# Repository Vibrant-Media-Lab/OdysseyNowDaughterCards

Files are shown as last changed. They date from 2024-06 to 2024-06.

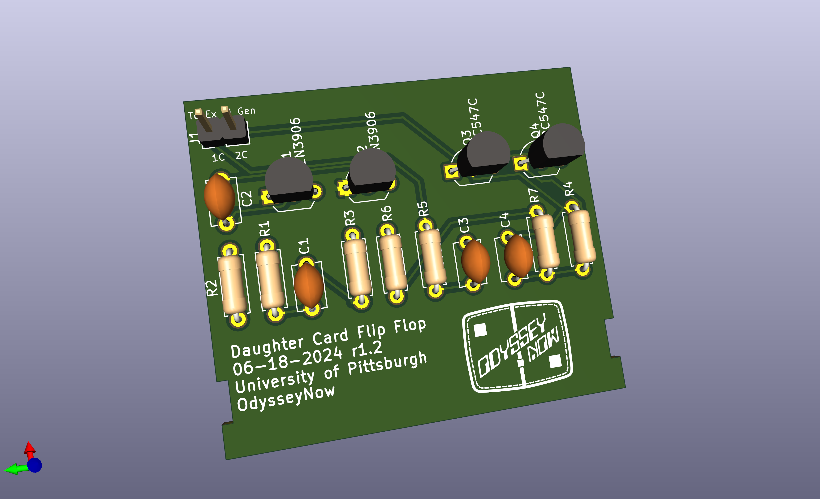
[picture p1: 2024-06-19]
OdysseyDaughterCardFlipFlop/images/OdysseyDaughterCardFlipFlop.png

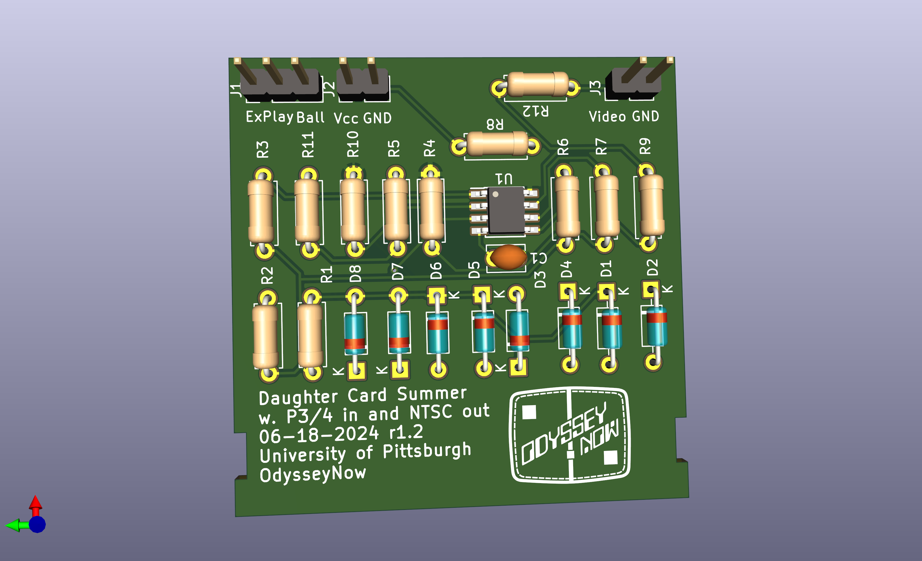
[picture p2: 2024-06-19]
OdysseyDaughterCardSummer/images/OdysseyDaughterCardSummer.png

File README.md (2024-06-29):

# Odyssey Now Daughter Cards

Replacement daughter card schematics and layouts for the Magnavox Odyssey BLAK version.

## Layout
* `OdysseyDaughterCard<name>` (KiCad 8 project)
  * `3D_models/` (WRL and STEP files for the board)
  * `footprints/` (non-standard footprint libraries for project)
  * `gerbers/` (last generated gerbers for layout)
  * `images/` (a render of the board)
  * `pdf/` (pdfs of schematic and layout)
  * `symbols/` (non-standard symbol libraries for project)
  * `dimensions.txt` (board dimension in meters for easier ordering from places like AllPCB)

## Bill of Materials
* See OdysseyDaughtCardsBillOfMaterials.xlsx for a list components used in the last round of boards made in the VML.

## License
* Designed by Levi Burner and Zachary Horton
* Each card's design is available under Creative Commons Attribution. All license text must be included in any redistribution and attribution must be given to original design and designers. See LICENSE.txt in each card's folder for additional details.

## Old Designs (legacy)
The original git history for each card (including old prototypes that were made and are likely to be floating around in the VML) be found on the `legacy-*` branches.

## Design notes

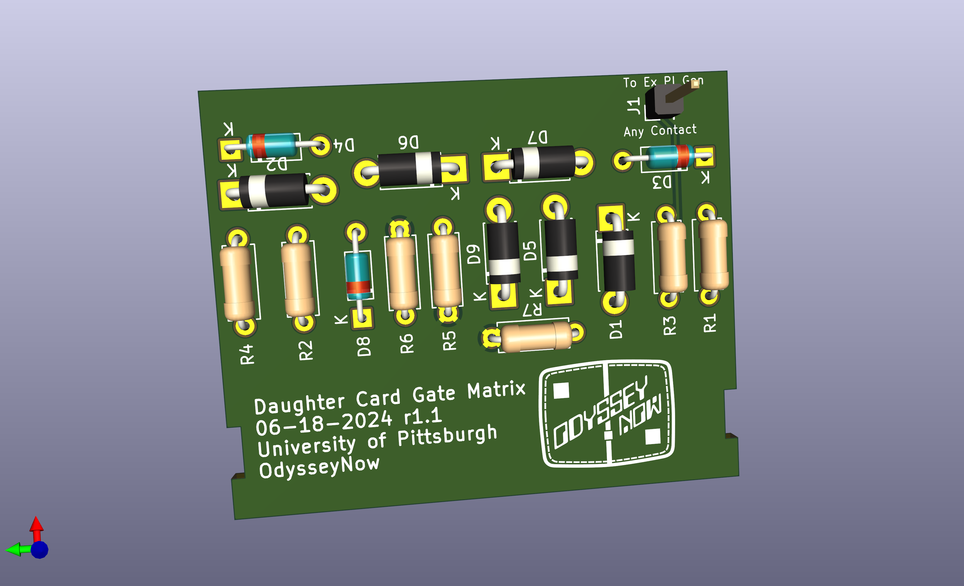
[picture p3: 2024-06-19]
OdysseyDaughterCardGateMatrix/images/OdysseyDaughterCardGateMatrix.png

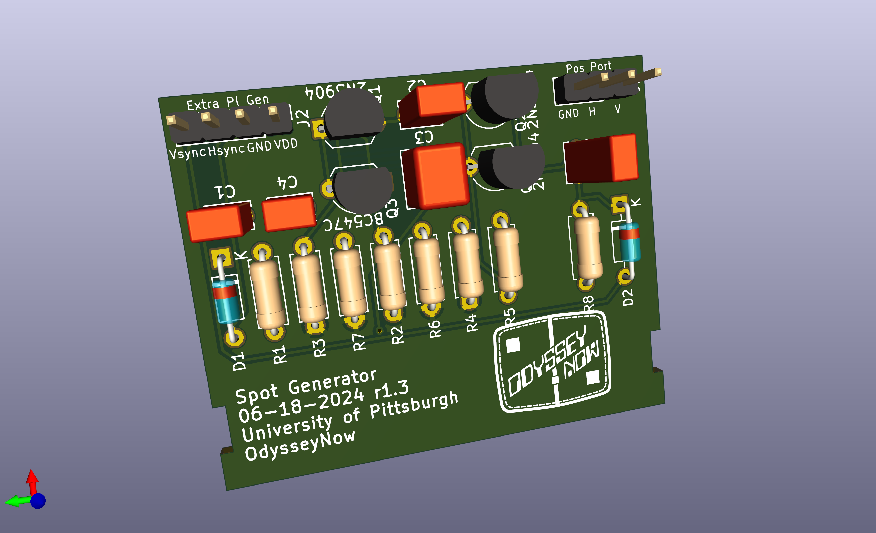
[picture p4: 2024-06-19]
OdysseyDaughterCardSpotGenerator/images/OdysseyDaughterCardSpotGenerator.png

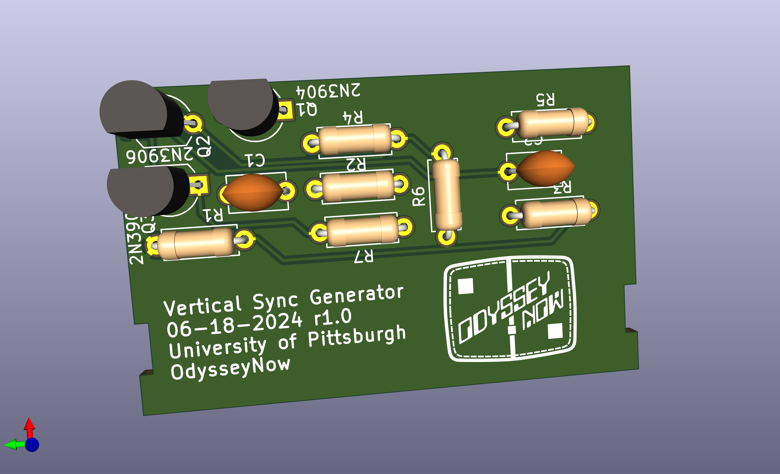
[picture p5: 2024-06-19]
OdysseyDaughterCardVertSyncGenerator/images/OdysseyDaughterCardVertSyncGenerator.png

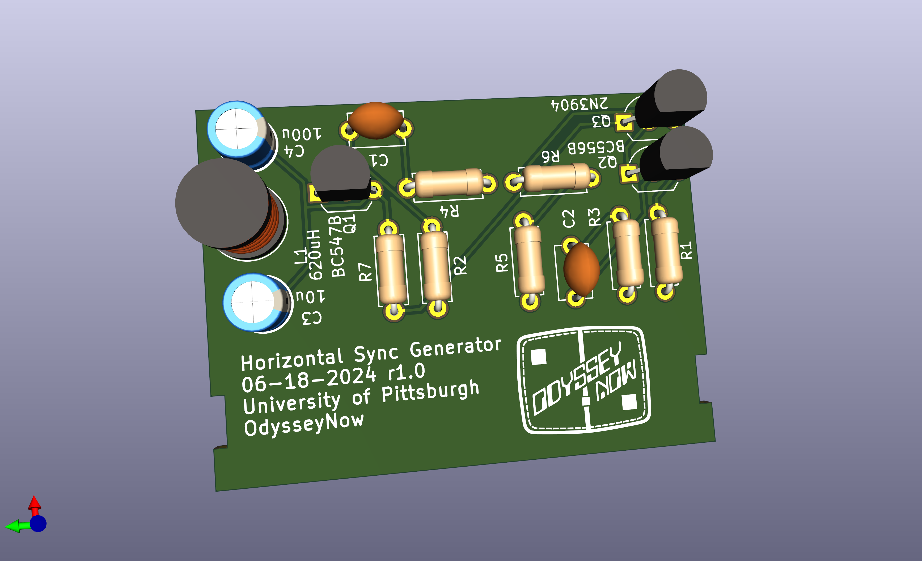
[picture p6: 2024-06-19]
OdysseyDaughterCardHorizSyncGenerator/images/OdysseyDaughterCardHorizSyncGenerator.png

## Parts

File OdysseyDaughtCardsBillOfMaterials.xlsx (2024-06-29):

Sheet: Master Parts List
 |  |  |  |  |  | # Parts | 19 | 12 | 15 | 19 | 15 | 11
 |  |  |  |  |  | Non PCB Cost Per Unit (10pcs) | $1.61 | $2.27 | $1.64 | $2.07 | $2.07 | $1.18
 |  |  |  |  |  | Non PCB Cost Per Unit (100pcs) | $0.81 | $1.19 | $0.79 | $1.01 | $1.09 | $0.55
Type | Value | P/N | Link | Notes | CPU (10pcs) | CPU (100pcs) (prices are from 2019) | Flip Flop | Gate Matrix | Horiz Sync Generator | Spot Gen | Summer | Vert Sync Generator
Capacitor | 0.01u | BC2662CT-ND | https://www.digikey.com/product-detail/en/vishay-bc-components/K103K10X7RF5UH5/BC2662CT-ND/2356876 |  | $0.118 | $0.0599 |  |  |  | 1
Capacitor | 0.15u | 445-173584-1-ND | https://www.digikey.com/product-detail/en/tdk-corporation/FG28X7R1E154KNT06/445-173584-1-ND/5812189 |  | $0.180 | $0.1021 |  |  |  | 1
Capacitor | 0.1u | BC2665CT-ND | https://www.digikey.com/product-detail/en/vishay-bc-components/K104K10X7RF5UH5/BC2665CT-ND/2356879 |  | $0.160 | $0.0809 | 2 |  |  | 1 |  | 2
Capacitor | 100p | BC2657CT-ND | https://www.digikey.com/product-detail/en/vishay-bc-components/K101K10X7RF5UH5/BC2657CT-ND/2356871 |  | $0.122 | $0.0621 | 2
Capacitor | 100u | 399-6602-ND | https://www.digikey.com/product-detail/en/kemet/ESK107M6R3AC3AA/399-6602-ND/3083017 |  | $0.114 | $0.0534 |  |  | 1
Capacitor | 10u | 399-6597-ND | https://www.digikey.com/product-detail/en/kemet/ESK106M016AC3AA/399-6597-ND/3083012 |  | $0.105 | $0.0493 |  |  | 1
Capacitor | 120p | BC2669CT-ND | https://www.digikey.com/product-detail/en/vishay-bc-components/K121K10X7RF5UH5/BC2669CT-ND/2356883 |  | $0.120 | $0.0608 |  |  |  | 1
Capacitor | 1500p | 445-173589-1-ND | https://www.digikey.com/product-detail/en/tdk-corporation/FG28X7R1H152KNT06/445-173589-1-ND/5812194 |  | $0.180 | $0.1021 |  |  |  | 1
Capacitor | 470p | BC2681CT-ND | https://www.digikey.com/product-detail/en/vishay-bc-components/K471K10X7RF5UH5/BC2681CT-ND/2356895 |  | $0.120 | $0.0608 |  |  | 1
Capacitor | 680p | BC2690CT-ND | https://www.digikey.com/product-detail/en/vishay-bc-components/K681K10X7RF5UH5/BC2690CT-ND/2356904 |  | $0.123 | $0.0625 |  |  | 1
Diode | 1N4448 | 1N4448FS-ND | https://www.digikey.com/product-detail/en/on-semiconductor/1N4448/1N4448FS-ND/978532 |  | $0.087 | $0.0473 |  | 3 |  | 2 | 8
Diode | BAT83S | BAT83S-TRGICT-ND | https://www.digikey.com/product-detail/en/vishay-semiconductor-diodes-division/BAT83S-TR/BAT83S-TRGICT-ND/8564711 |  | $0.314 | $0.1664 |  | 6 |  |  | 4
Inductor | 620uH 9 Ohm | RLB0608-681KL-ND | https://www.digikey.com/product-detail/en/bourns-inc/RLB0608-681KL/RLB0608-681KL-ND/2561280 |  | $0.314 | $0.1664 |  |  | 1
Resistor | 470 | CF14JT470RCT-ND | https://www.digikey.com/product-detail/en/stackpole-electronics-inc/CF14JT470R/CF14JT470RCT-ND/1830342 |  | $0.040 | $0.0162 |  |  | 1 |  |  | 2
Resistor | 820 | CF14JT820RCT-ND | https://www.digikey.com/product-detail/en/stackpole-electronics-inc/CF14JT820R/CF14JT820RCT-ND/1830348 |  | $0.040 | $0.0162 |  |  | 1 |  | 1 | 1
Resistor | 100k | CF14JT100KCT-ND | https://www.digikey.com/product-detail/en/stackpole-electronics-inc/CF14JT100K/CF14JT100KCT-ND/1830399 |  | $0.040 | $0.0162 |  |  |  | 1
Resistor | 10k | CF14JT10K0CT-ND | https://www.digikey.com/product-detail/en/stackpole-electronics-inc/CF14JT10K0/CF14JT10K0CT-ND/1830374 |  | $0.040 | $0.0162 |  |  |  | 5
Resistor | 150k | CF14JT150KCT-ND | https://www.digikey.com/product-detail/en/stackpole-electronics-inc/CF14JT150K/CF14JT150KCT-ND/1830403 |  | $0.040 | $0.0162 |  |  | 1
Resistor | 180k | CF14JT180KCT-ND | https://www.digikey.com/products/en?keywords=CF14JT180KCT-ND |  | $0.040 | $0.0162 |  |  |  |  |  | 1
Resistor | 18k | CF14JT18K0CT-ND | https://www.digikey.com/product-detail/en/stackpole-electronics-inc/CF14JT18K0/CF14JT18K0CT-ND/1830381 |  | $0.040 | $0.0162 |  |  |  |  | 1
Resistor | 1k | CF14JT1K00CT-ND | https://www.digikey.com/product-detail/en/stackpole-electronics-inc/CF14JT1K00/CF14JT1K00CT-ND/1830350 |  | $0.040 | $0.0162 | 2 |  | 2
Resistor | 2.2k | CF14JT2K20CT-ND | https://www.digikey.com/product-detail/en/stackpole-electronics-inc/CF14JT2K20/CF14JT2K20CT-ND/1830358 |  | $0.040 | $0.0162 | 1 |  |  | 1 |  | 1
Resistor | 270k | CF14JT270KCT-ND | https://www.digikey.com/product-detail/en/stackpole-electronics-inc/CF14JT270K/CF14JT270KCT-ND/1830409 |  | $0.040 | $0.0162 |  |  |  | 1
Resistor | 27k | CF14JT27K0CT-ND | https://www.digikey.com/product-detail/en/stackpole-electronics-inc/CF14JT27K0/CF14JT27K0CT-ND/1830385 |  | $0.040 | $0.0162 |  |  |  |  | 1
Resistor | 3.3k | CF14JT3K30CT-ND | https://www.digikey.com/product-detail/en/stackpole-electronics-inc/CF14JT3K30/CF14JT3K30CT-ND/1830362 |  | $0.040 | $0.0162 |  |  | 1
Resistor | 300k | CF14JT300KCT-ND | https://www.digikey.com/product-detail/en/stackpole-electronics-inc/CF14JT300K/CF14JT300KCT-ND/1830410 |  | $0.040 | $0.0162 |  |  | 1 |  |  | 1
Resistor | 4.7k | CF14JT4K70CT-ND | https://www.digikey.com/product-detail/en/stackpole-electronics-inc/CF14JT4K70/CF14JT4K70CT-ND/1830366 |  | $0.040 | $0.0162 |  | 3
Resistor | 47k | CF14JT47K0CT-ND | https://www.digikey.com/product-detail/en/stackpole-electronics-inc/CF14JT47K0/CF14JT47K0CT-ND/1830391 |  | $0.040 | $0.0162 | 4
Switch/Button | Slide Switch SPDT Through Hole, Right Angle | CKN9559-ND | https://www.digikey.com/product-detail/en/c-k/OS102011MA1QN1/CKN9559-ND/1981430 |  |  |  | 4
Transistor | 2N3904 | 2N3904FS-ND | https://www.digikey.com/product-detail/en/on-semiconductor/2N3904BU/2N3904FS-ND/1413 |  | $0.210 | $0.0916 |  |  | 1 | 3 |  | 2
Transistor | 2N3906 | 2N3906TARFSCT-ND | https://www.digikey.com/product-detail/en/on-semiconductor/2N3906TAR/2N3906TARFSCT-ND/3478146 |  | $0.195 | $0.1035 | 2 |  |  |  |  | 1
Transistor | BC547B | BC547BTACT-ND | https://www.digikey.com/product-detail/en/on-semiconductor/BC547BTA/BC547BTACT-ND/1532789 |  | $0.181 | $0.0962 |  |  | 1
Transistor | BC547C | BC547CBU-ND | https://www.digikey.com/product-detail/en/on-semiconductor/BC547CBU/BC547CBU-ND/975543 |  | $0.190 | $0.1005 | 2 |  |  | 1
Transistor | BC556B | BC556BTACT-ND | https://www.digikey.com/product-detail/en/on-semiconductor/BC556BTA/BC556BTACT-ND/3042483 |  | $0.188 | $0.0999 |  |  | 1

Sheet: Digikey Order Generator
This sheet can be used to generate a BOM to import into the Digikey
 | Extra parts multiplier | 1.2 |  | Flip Flop | Gate Matrix | Horiz Sync Generator | Spot Gen | Summer | Vert Sync Generator
 |  |  | Number of Assemblies | 16 | 16 | 0 | 30 | 30 | 0
Type | Value | P/N | Number of parts to order
Capacitor | 0.01u | BC2662CT-ND | 36 | 0 | 0 | 0 | 30 | 0 | 0
Capacitor | 0.15u | 445-173584-1-ND | 36 | 0 | 0 | 0 | 30 | 0 | 0
Capacitor | 0.1u | BC2665CT-ND | 75 | 32 | 0 | 0 | 30 | 0 | 0
Capacitor | 100p | BC2657CT-ND | 39 | 32 | 0 | 0 | 0 | 0 | 0
Capacitor | 100u | 399-6602-ND | 0 | 0 | 0 | 0 | 0 | 0 | 0
Capacitor | 10u | 399-6597-ND | 0 | 0 | 0 | 0 | 0 | 0 | 0
Capacitor | 120p | BC2669CT-ND | 36 | 0 | 0 | 0 | 30 | 0 | 0
Capacitor | 1500p | 445-173589-1-ND | 36 | 0 | 0 | 0 | 30 | 0 | 0
Capacitor | 470p | BC2681CT-ND | 0 | 0 | 0 | 0 | 0 | 0 | 0
Capacitor | 680p | BC2690CT-ND | 0 | 0 | 0 | 0 | 0 | 0 | 0
Diode | 1N4448 | 1N4448FS-ND | 418 | 0 | 48 | 0 | 60 | 240 | 0
Diode | BAT83S | BAT83S-TRGICT-ND | 260 | 0 | 96 | 0 | 0 | 120 | 0
Inductor | 620uH 9 Ohm | RLB0608-681KL-ND | 0 | 0 | 0 | 0 | 0 | 0 | 0
Resistor | 470 | CF14JT470RCT-ND | 0 | 0 | 0 | 0 | 0 | 0 | 0
Resistor | 820 | CF14JT820RCT-ND | 36 | 0 | 0 | 0 | 0 | 30 | 0
Resistor | 100k | CF14JT100KCT-ND | 36 | 0 | 0 | 0 | 30 | 0 | 0
Resistor | 10k | CF14JT10K0CT-ND | 180 | 0 | 0 | 0 | 150 | 0 | 0
Resistor | 150k | CF14JT150KCT-ND | 0 | 0 | 0 | 0 | 0 | 0 | 0
Resistor | 180k | CF14JT180KCT-ND | 0 | 0 | 0 | 0 | 0 | 0 | 0
Resistor | 18k | CF14JT18K0CT-ND | 36 | 0 | 0 | 0 | 0 | 30 | 0
Resistor | 1k | CF14JT1K00CT-ND | 39 | 32 | 0 | 0 | 0 | 0 | 0
Resistor | 2.2k | CF14JT2K20CT-ND | 56 | 16 | 0 | 0 | 30 | 0 | 0
Resistor | 270k | CF14JT270KCT-ND | 36 | 0 | 0 | 0 | 30 | 0 | 0
Resistor | 27k | CF14JT27K0CT-ND | 36 | 0 | 0 | 0 | 0 | 30 | 0
Resistor | 3.3k | CF14JT3K30CT-ND | 0 | 0 | 0 | 0 | 0 | 0 | 0
Resistor | 300k | CF14JT300KCT-ND | 0 | 0 | 0 | 0 | 0 | 0 | 0
Resistor | 4.7k | CF14JT4K70CT-ND | 58 | 0 | 48 | 0 | 0 | 0 | 0
Resistor | 47k | CF14JT47K0CT-ND | 77 | 64 | 0 | 0 | 0 | 0 | 0
Switch/Button | Slide Switch SPDT Through Hole, Right Angle | CKN9559-ND | 77 | 64 | 0 | 0 | 0 | 0 | 0
Transistor | 2N3904 | 2N3904FS-ND | 108 | 0 | 0 | 0 | 90 | 0 | 0
Transistor | 2N3906 | 2N3906TARFSCT-ND | 39 | 32 | 0 | 0 | 0 | 0 | 0
Transistor | BC547B | BC547BTACT-ND | 0 | 0 | 0 | 0 | 0 | 0 | 0
Transistor | BC547C | BC547CBU-ND | 75 | 32 | 0 | 0 | 30 | 0 | 0
Transistor | BC556B | BC556BTACT-ND | 0 | 0 | 0 | 0 | 0 | 0 | 0

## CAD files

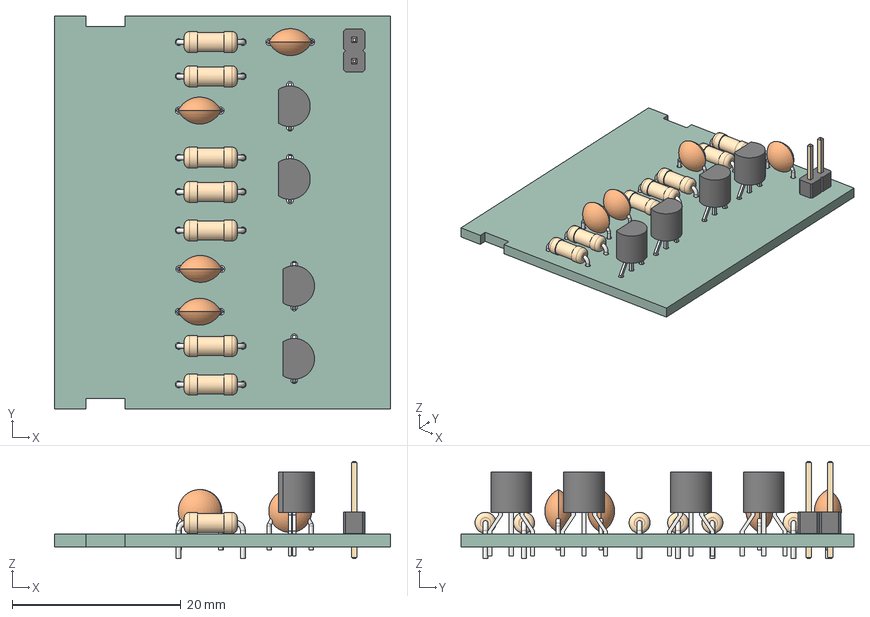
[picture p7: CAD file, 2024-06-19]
OdysseyDaughterCardFlipFlop/3D_models/OdysseyDaughterCardFlipFlop.step
39.9 x 46.6 x 11.5 mm
C_Disc_D51mm_W32mm_P500mm x 4
TO-92_Inline_Wide x 4
R_Axial_DIN0207_L63mm_D25mm_P762mm_Horizontal x 7
PinHeader_1x02_P254mm_Vertical
_autosave-OdysseyDaughterCardFlipFlop_PCB

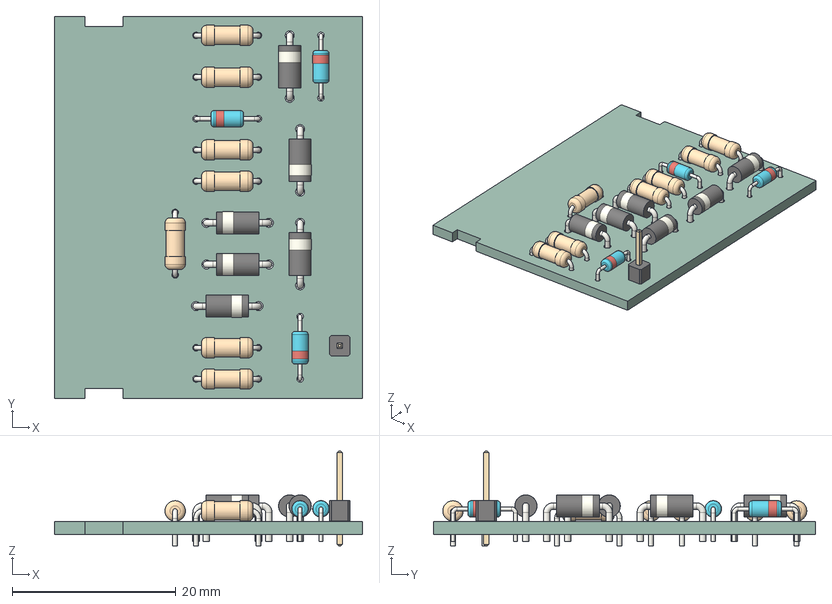
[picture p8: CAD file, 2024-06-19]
OdysseyDaughterCardGateMatrix/3D_models/OdysseyDaughterCardGateMatrix.step
37.6 x 46.6 x 11.5 mm
D_DO-41_SOD81_P7.62mm_Horizontal x 6
D_DO-35_SOD27_P7.62mm_Horizontal x 3
R_Axial_DIN0207_L63mm_D25mm_P762mm_Horizontal x 7
PinHeader_1x01_P254mm_Vertical
_autosave-OdysseyDaughterCardGateMatrix_PCB

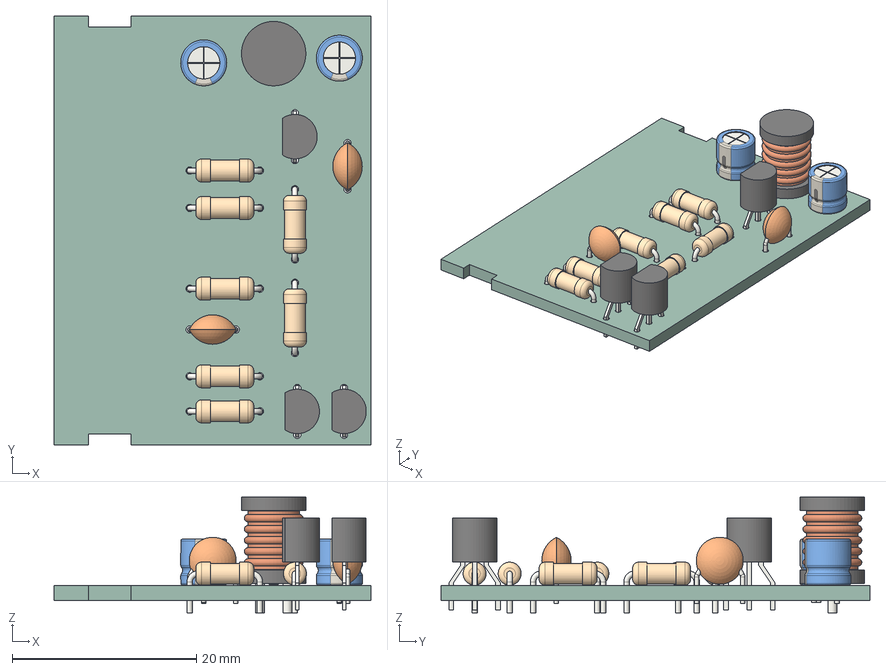
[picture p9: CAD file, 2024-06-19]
OdysseyDaughterCardHorizSyncGenerator/3D_models/OdysseyDaughterCardHorizSyncGenerator.step
34.4 x 46.6 x 12.6 mm
C_Disc_D51mm_W32mm_P500mm x 2
CP_Radial_D50mm_P200mm x 2
L_Radial_D7.0mm_P3.00mm
TO-92_Inline_Wide x 3
R_Axial_DIN0207_L63mm_D25mm_P762mm_Horizontal x 7
_autosave-OdysseyDaughterCardHorizSyncGenerator_PCB

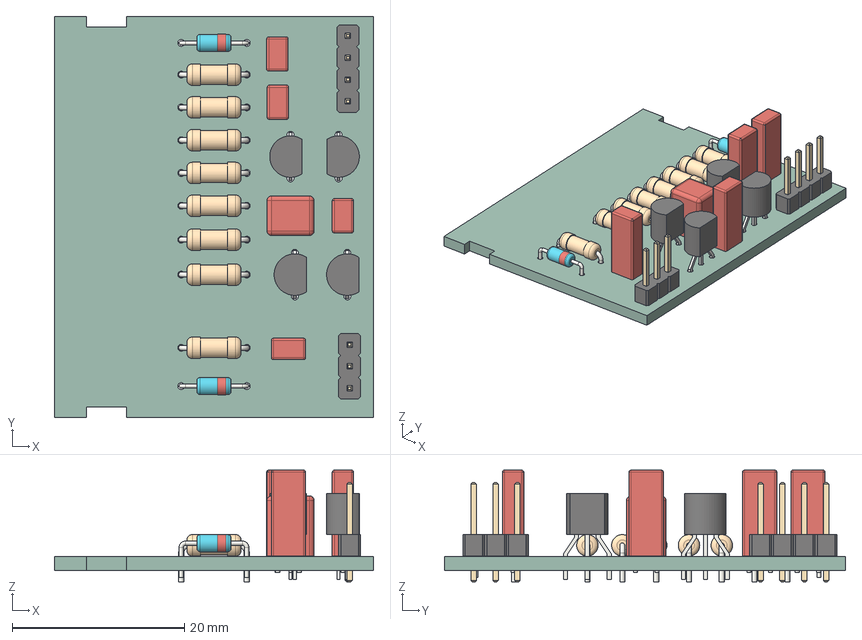
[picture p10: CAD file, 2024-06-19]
OdysseyDaughterCardSpotGenerator/3D_models/OdysseyDaughterCardSpotGenerator.step
37.1 x 46.6 x 13.0 mm
C_Rect_L40mm_W25mm_P250mm x 4
C_Rect_L46mm_W55mm_P250mm_MKS02_FKP02
D_DO-35_SOD27_P7.62mm_Horizontal x 2
TO-92_Inline_Wide x 4
R_Axial_DIN0207_L63mm_D25mm_P762mm_Horizontal x 8
PinHeader_1x03_P254mm_Vertical
PinHeader_1x04_P254mm_Vertical
_autosave-OdysseyDaughterCardSpotGenerator_PCB

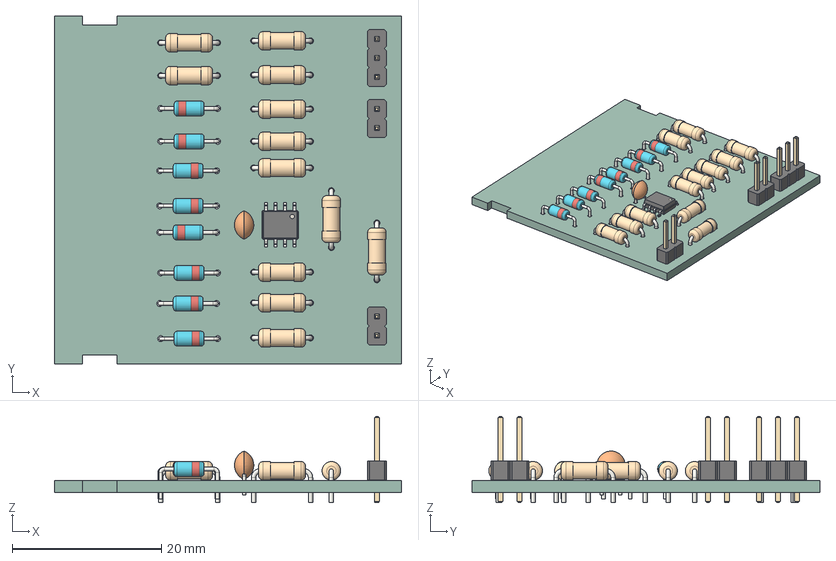
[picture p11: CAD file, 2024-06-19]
OdysseyDaughterCardSummer/3D_models/OdysseyDaughterCardSummer.step
46.5 x 46.6 x 11.5 mm
D_DO-35_SOD27_P7.62mm_Horizontal x 8
R_Axial_DIN0207_L63mm_D25mm_P762mm_Horizontal x 12
C_Disc_D38mm_W26mm_P250mm
PinHeader_1x02_P254mm_Vertical x 2
SOIC_8_39x49mm_P127mm
PinHeader_1x03_P254mm_Vertical
_autosave-OdysseyDaughterCardSummer_PCB

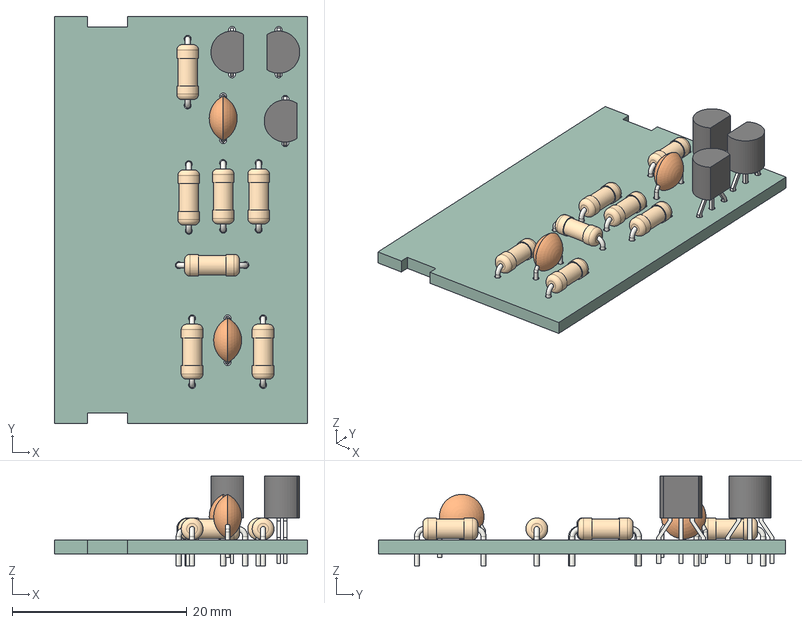
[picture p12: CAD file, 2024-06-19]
OdysseyDaughterCardVertSyncGenerator/3D_models/OdysseyDaughterCardVertSyncGenerator.step
29.0 x 46.6 x 10.3 mm
C_Disc_D51mm_W32mm_P500mm x 2
TO-92_Inline_Wide x 3
R_Axial_DIN0207_L63mm_D25mm_P762mm_Horizontal x 7
_autosave-OdysseyDaughterCardVertSyncGenerator_PCB

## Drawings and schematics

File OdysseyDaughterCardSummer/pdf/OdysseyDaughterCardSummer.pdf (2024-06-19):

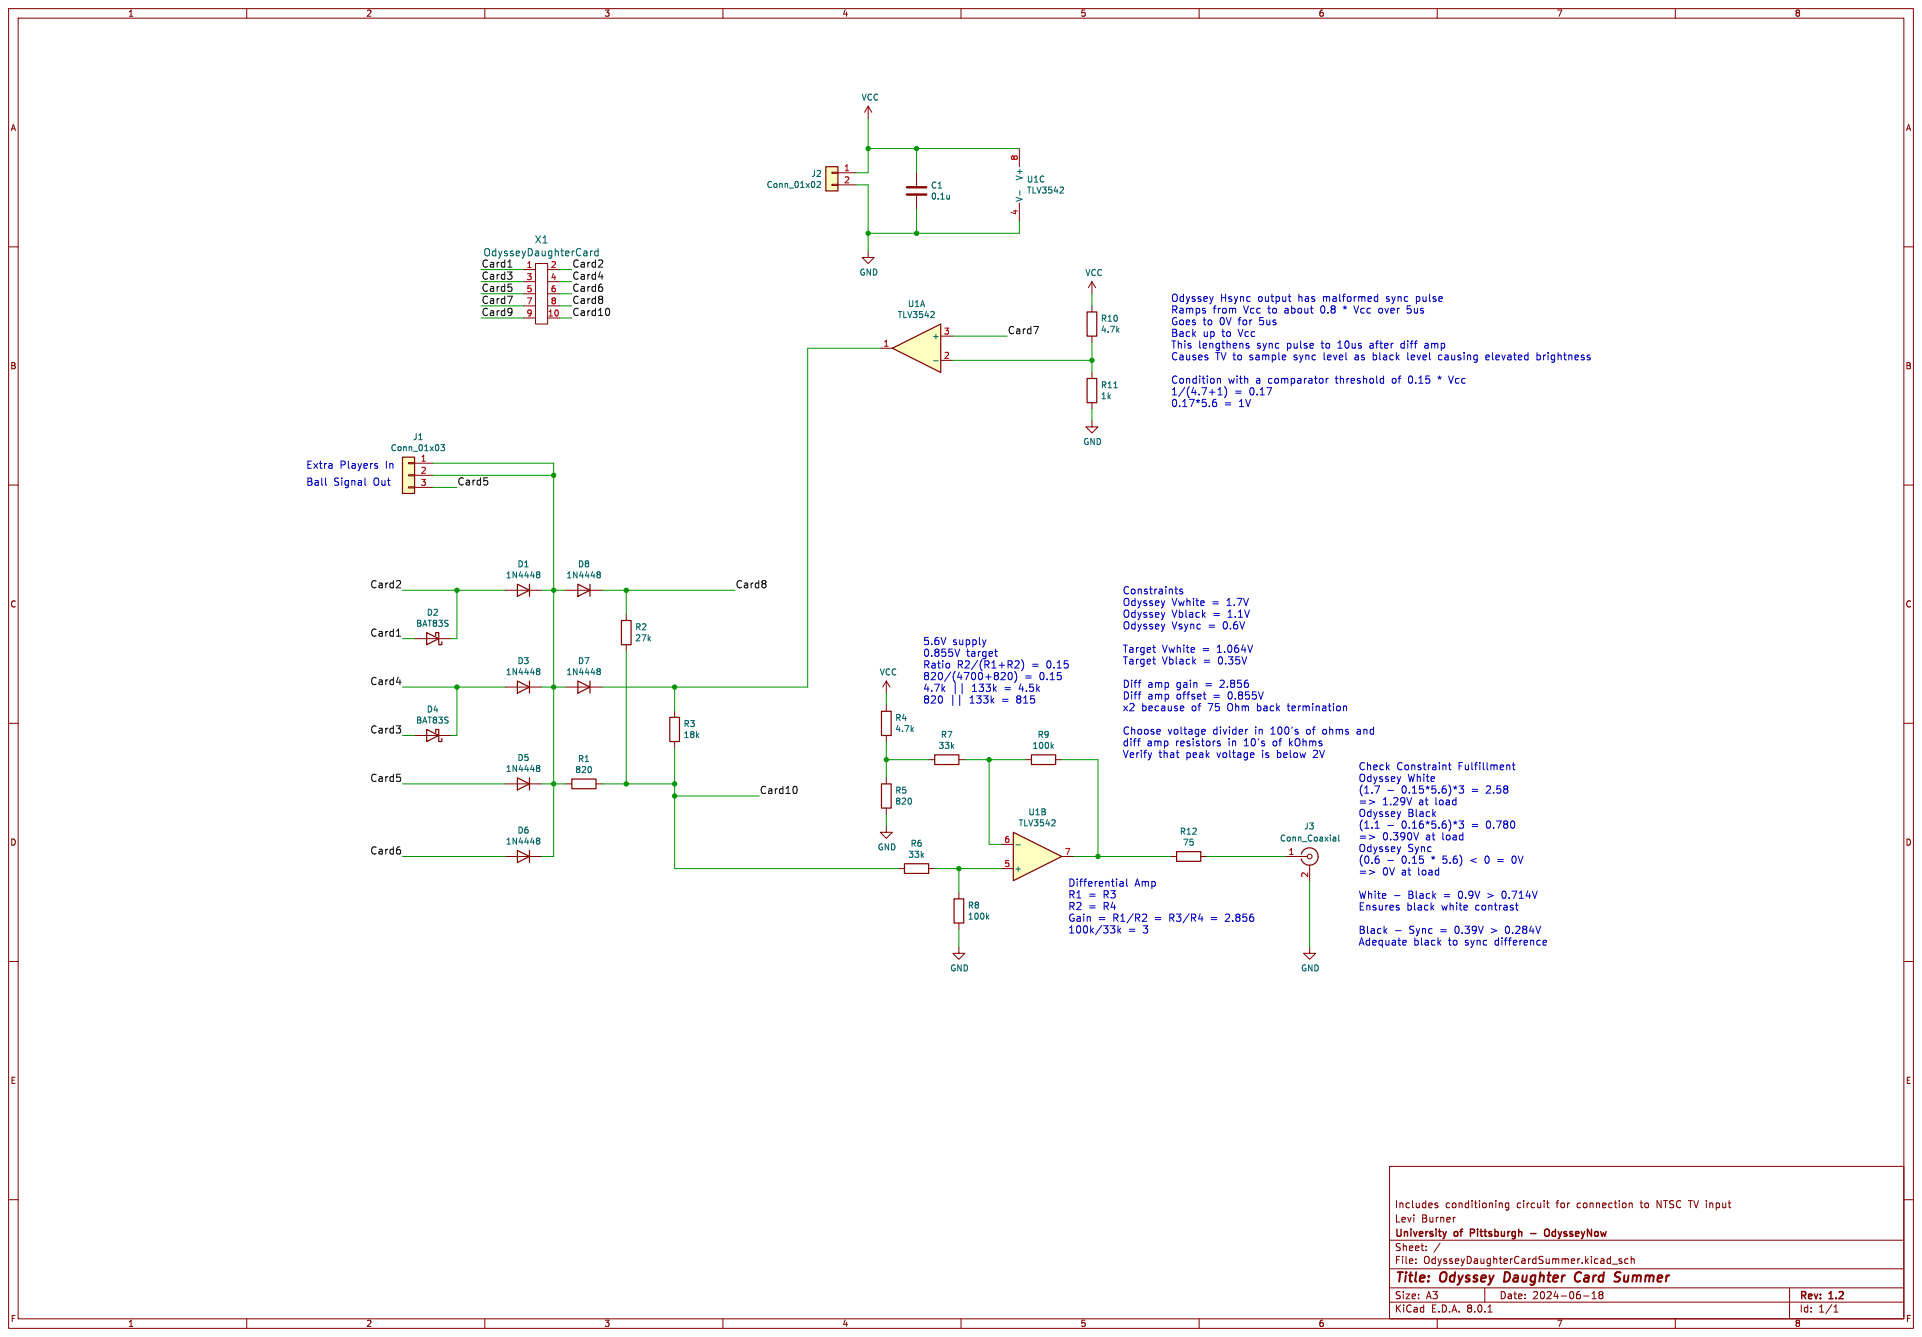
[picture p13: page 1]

Card10 Extra Players In Ball Signal Out

Adequate black to sync difference Constraints
Odyssey Vwhite = 1.7V Odyssey Vblack = 1.1V Odyssey Vsync = 0.6V

Target Vwhite = 1.064V
Target Vblack = 0.35V Diff amp gain = 2.856 Diff amp offset = 0.855V

x2 because of 75 Ohm back termination Choose voltage divider in 100's of ohms and

=> 0V at load White - Black = 0.9V > 0.714V

Ensures black white contrast Black - Sync = 0.39V > 0.284V

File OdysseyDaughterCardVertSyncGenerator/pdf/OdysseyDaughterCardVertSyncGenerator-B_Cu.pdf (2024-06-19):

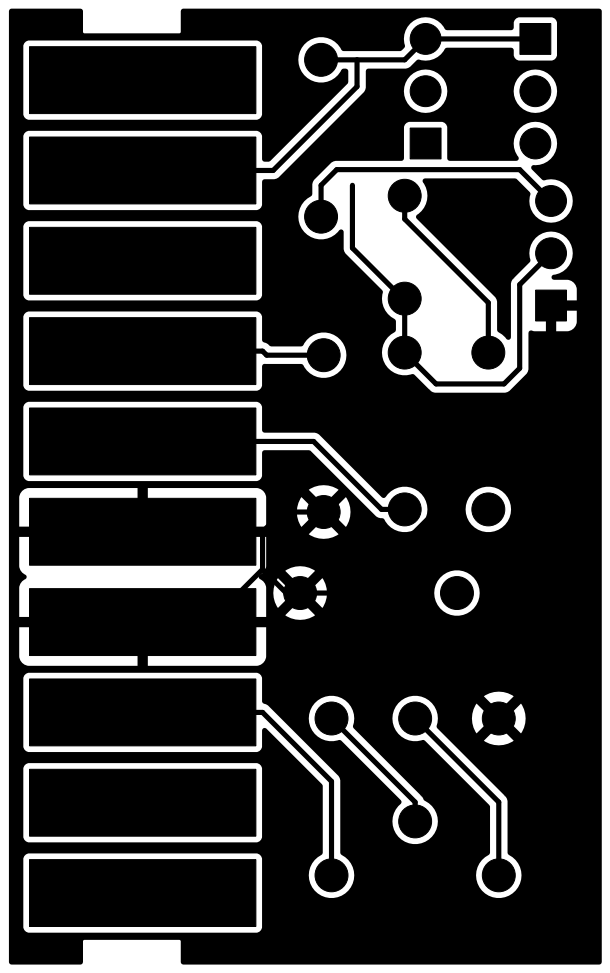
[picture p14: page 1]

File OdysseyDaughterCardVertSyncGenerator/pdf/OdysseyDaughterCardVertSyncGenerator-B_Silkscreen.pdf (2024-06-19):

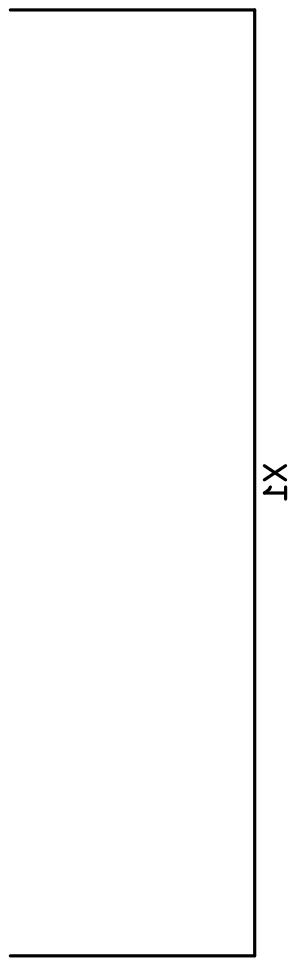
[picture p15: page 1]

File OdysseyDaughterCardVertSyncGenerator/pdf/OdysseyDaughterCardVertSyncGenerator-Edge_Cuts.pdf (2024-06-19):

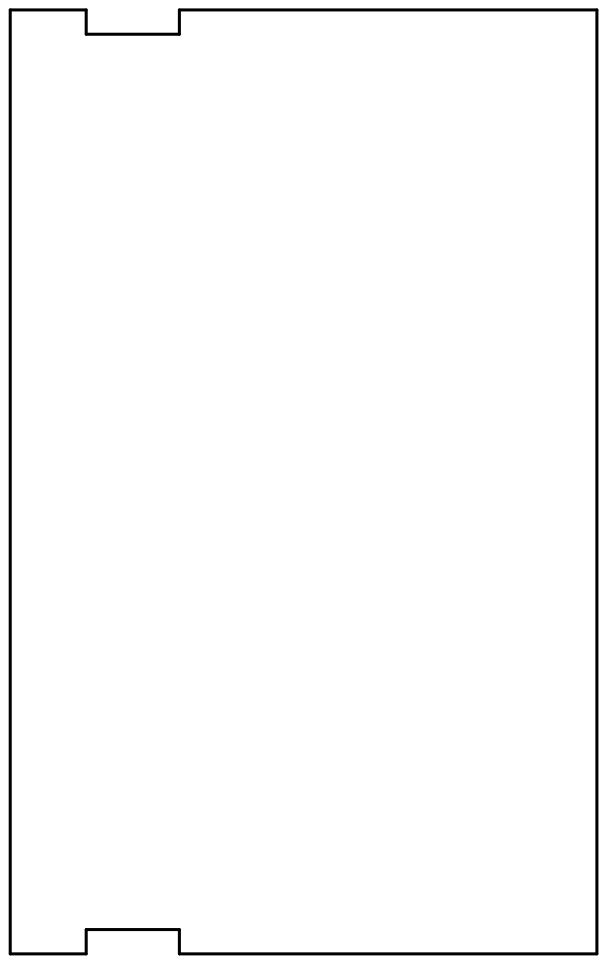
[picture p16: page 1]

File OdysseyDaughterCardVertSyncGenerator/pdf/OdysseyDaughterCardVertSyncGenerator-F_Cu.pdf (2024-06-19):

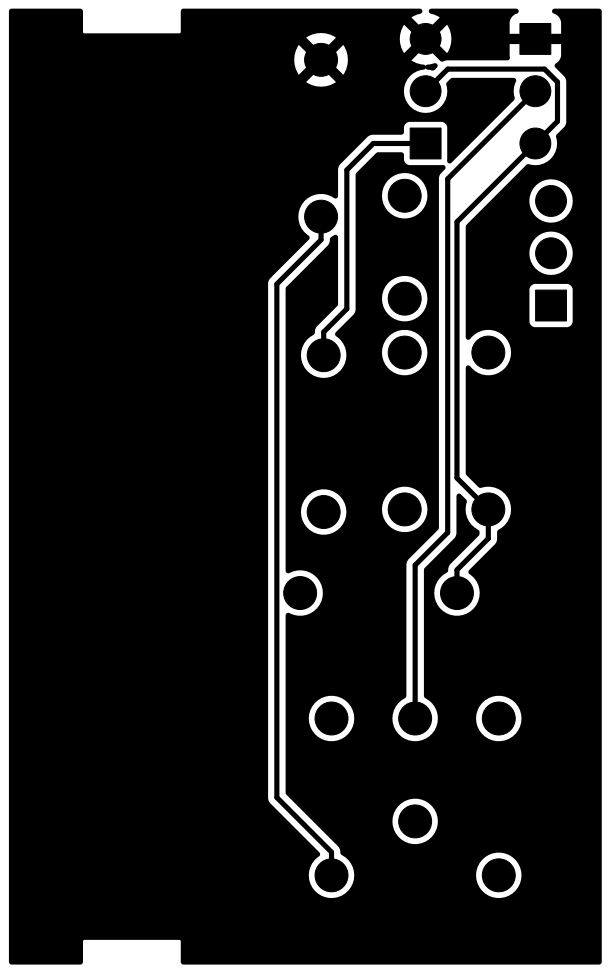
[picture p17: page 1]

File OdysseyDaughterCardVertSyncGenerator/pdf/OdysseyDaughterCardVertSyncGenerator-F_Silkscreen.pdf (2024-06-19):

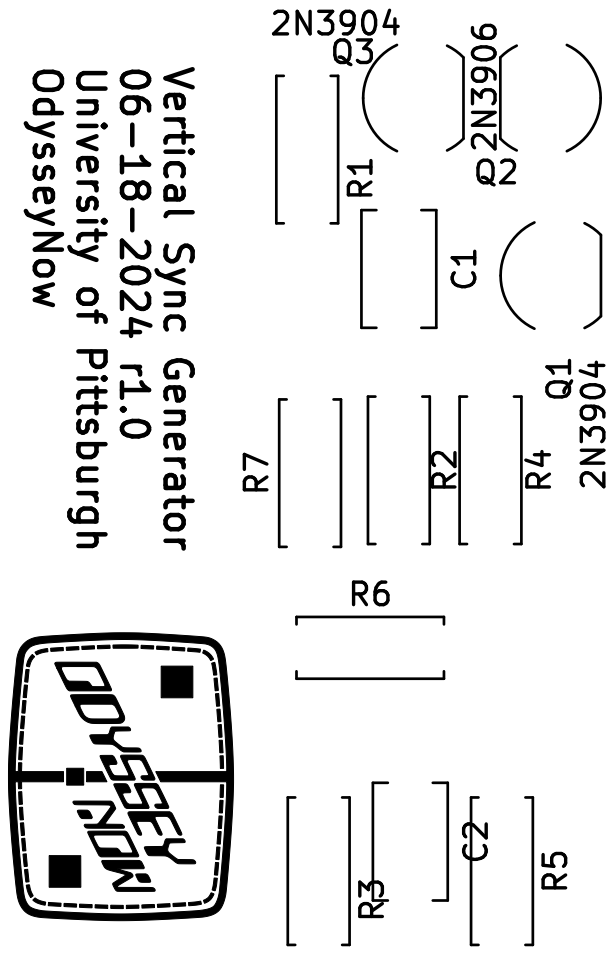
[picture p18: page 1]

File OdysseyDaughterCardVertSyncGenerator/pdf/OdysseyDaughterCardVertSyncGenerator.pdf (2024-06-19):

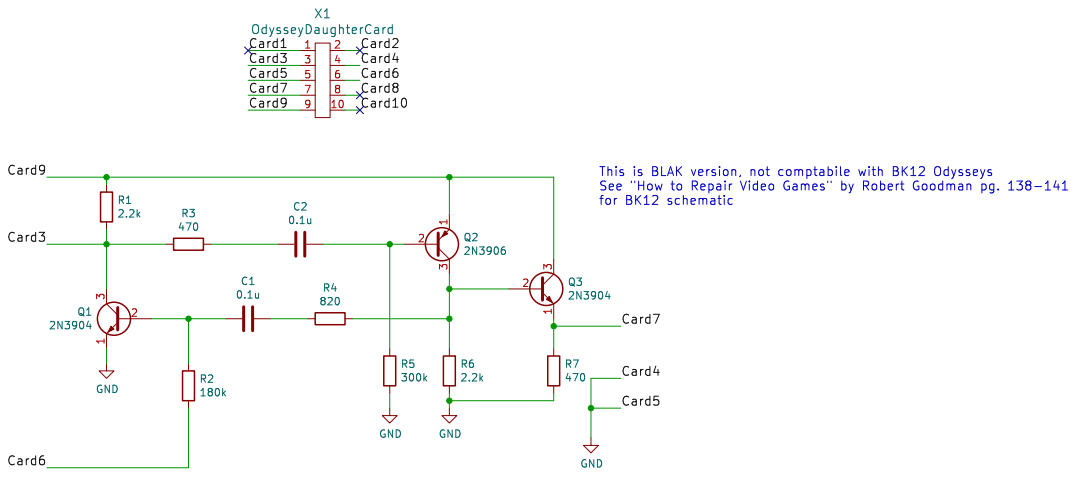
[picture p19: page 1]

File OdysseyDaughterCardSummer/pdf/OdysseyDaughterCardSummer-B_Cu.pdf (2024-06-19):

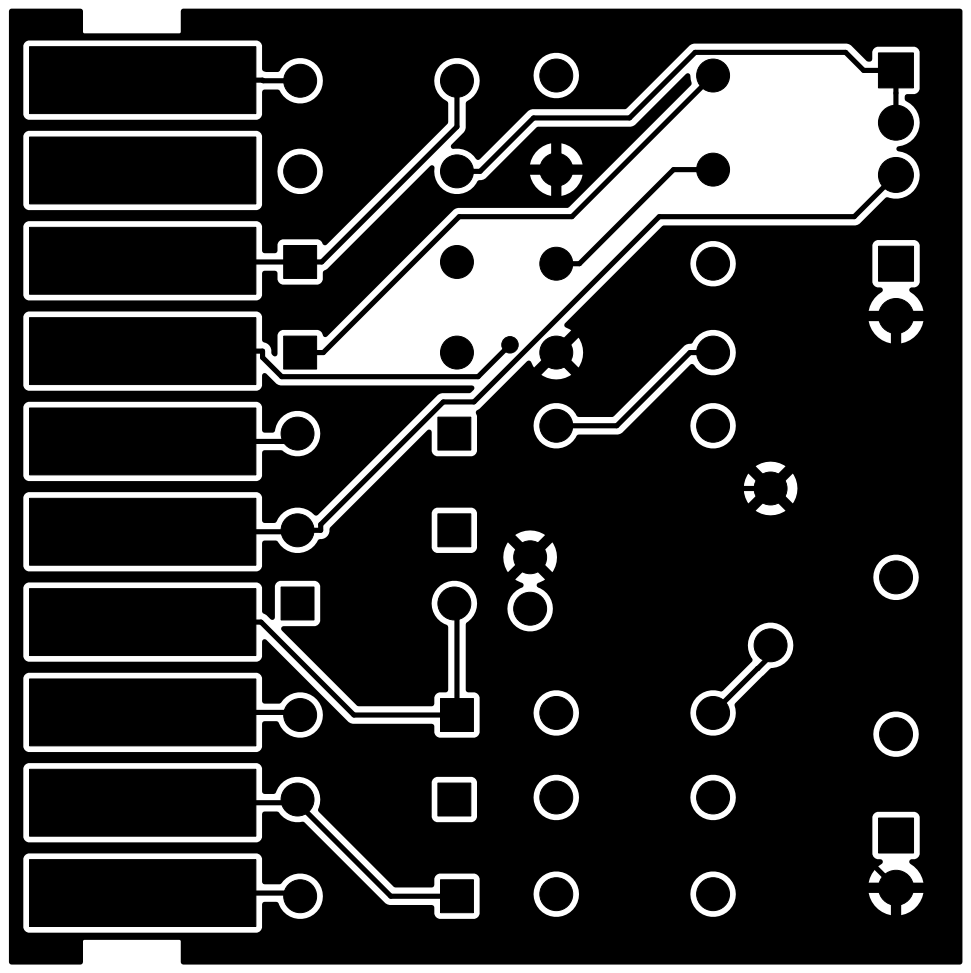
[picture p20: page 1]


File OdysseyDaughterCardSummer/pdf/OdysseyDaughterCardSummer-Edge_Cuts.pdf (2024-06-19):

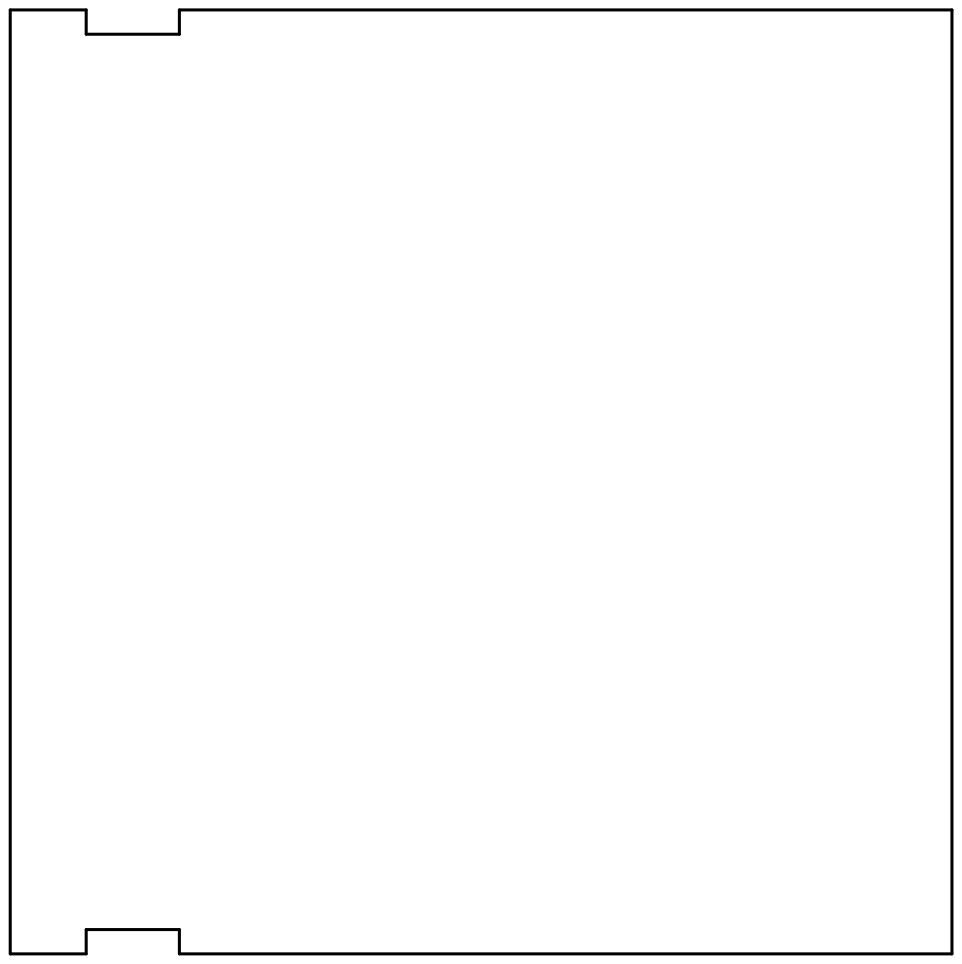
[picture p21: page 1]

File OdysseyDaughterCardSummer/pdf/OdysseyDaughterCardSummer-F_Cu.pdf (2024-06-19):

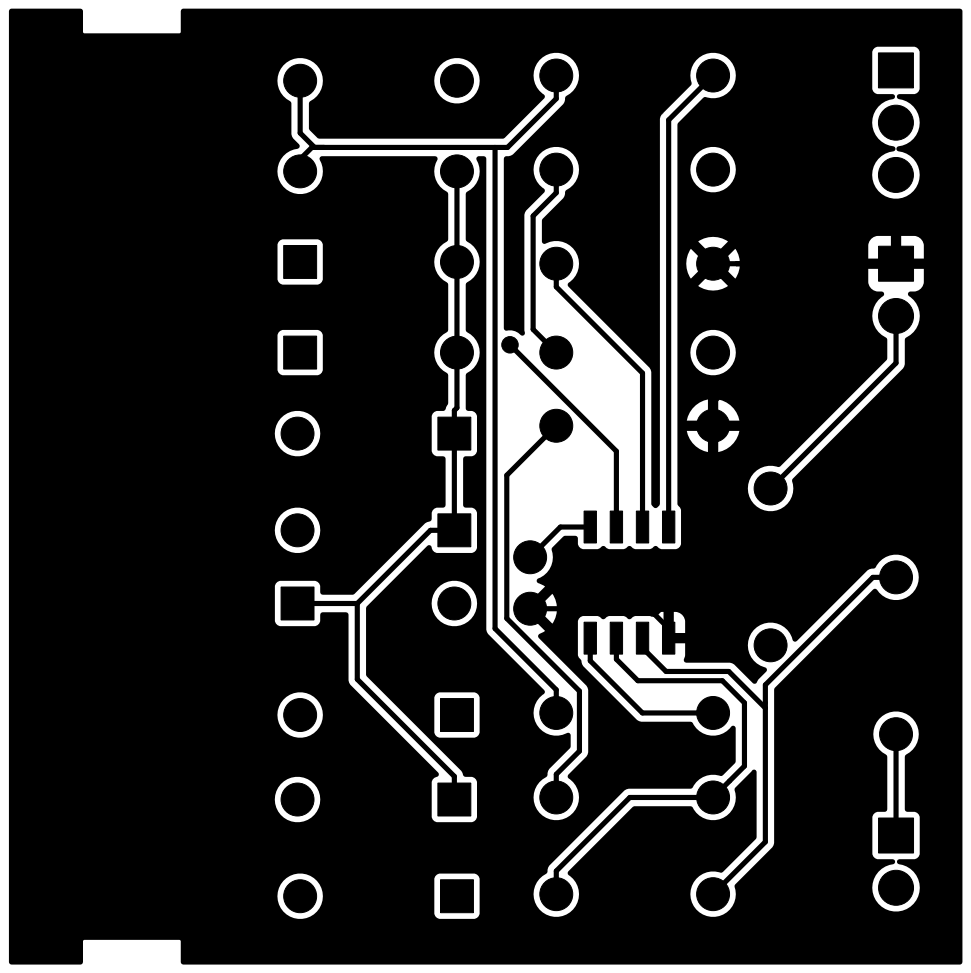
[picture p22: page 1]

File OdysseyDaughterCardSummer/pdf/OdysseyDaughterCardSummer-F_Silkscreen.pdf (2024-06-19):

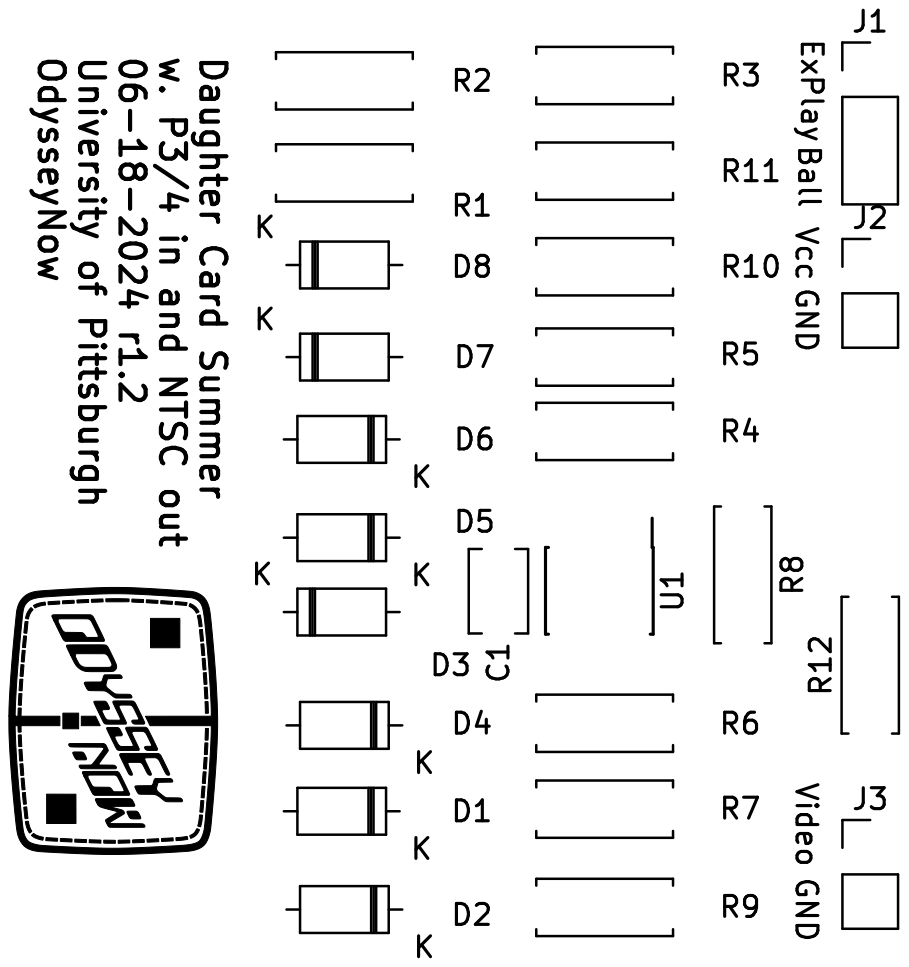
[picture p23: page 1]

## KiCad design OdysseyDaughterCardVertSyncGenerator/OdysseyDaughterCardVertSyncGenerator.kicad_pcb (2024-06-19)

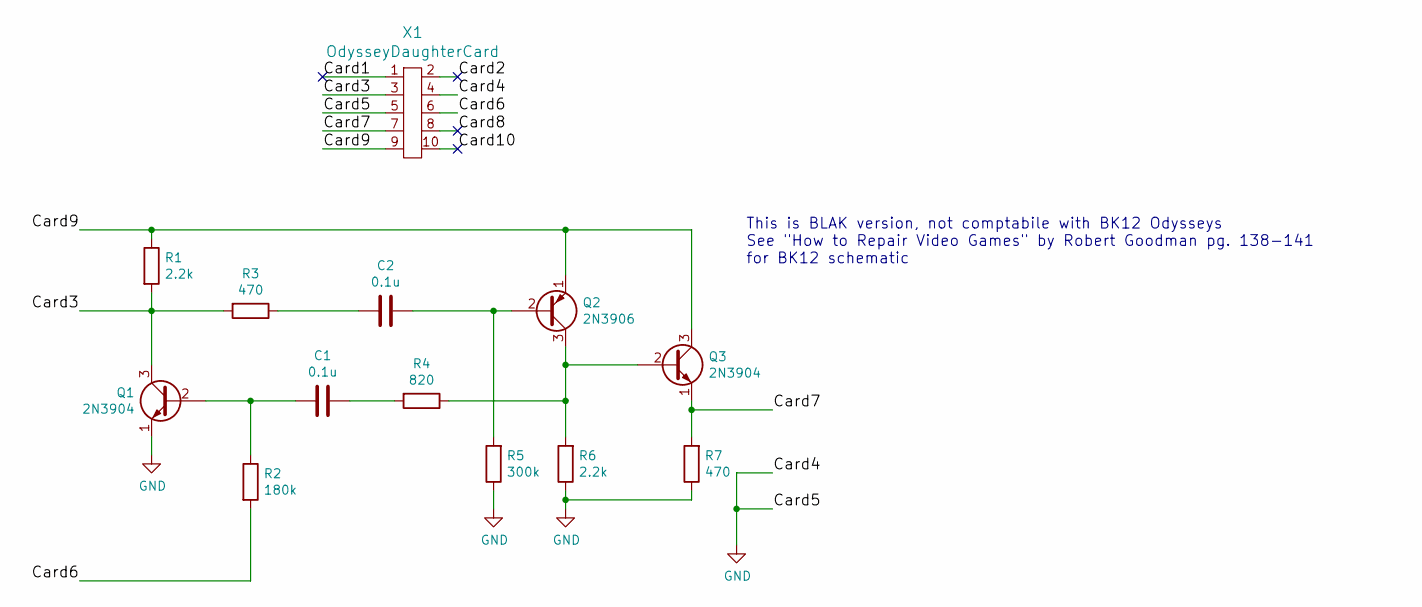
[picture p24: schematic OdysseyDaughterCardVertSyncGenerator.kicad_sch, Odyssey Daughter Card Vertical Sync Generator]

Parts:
C1, C2: 0.1u; C_Disc_D5.1mm_W3.2mm_P5.00mm
Q1, Q3: 2N3904; TO-92_Inline_Wide
Q2: 2N3906; TO-92_Inline_Wide
R1, R6: 2.2k; R_Axial_DIN0207_L6.3mm_D2.5mm_P7.62mm_Horizontal
R2: 180k; R_Axial_DIN0207_L6.3mm_D2.5mm_P7.62mm_Horizontal
R3, R7: 470; R_Axial_DIN0207_L6.3mm_D2.5mm_P7.62mm_Horizontal
R4: 820; R_Axial_DIN0207_L6.3mm_D2.5mm_P7.62mm_Horizontal
R5: 300k; R_Axial_DIN0207_L6.3mm_D2.5mm_P7.62mm_Horizontal
X1: OdysseyDaughterCard; Odyssey_Daughter_Card

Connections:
/Card1: X1.1
/Card2: X1.2
/Card3: Q1.3 (C), R1.2, R3.2, X1.3
/Card6: R2.2, X1.6
/Card7: Q3.1 (E), R7.2, X1.7
/Card8: X1.8
/Card9: Q2.1 (E), Q3.3 (C), R1.1, X1.9
/Card10: X1.10
GND: Q1.1 (E), R5.1, R6.1, R7.1, X1.4, X1.5
unnamed: C1.1, R4.2
unnamed: C2.2, R3.1
unnamed: C1.2, Q1.2 (B), R2.1
unnamed: C2.1, Q2.2 (B), R5.2
unnamed: Q2.3 (C), Q3.2 (B), R4.1, R6.2

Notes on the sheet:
This is BLAK version, not comptabile with BK12 Odysseys See "How to Repair Video Games" by Robert Goodman pg. 138-141 for BK12 schematic

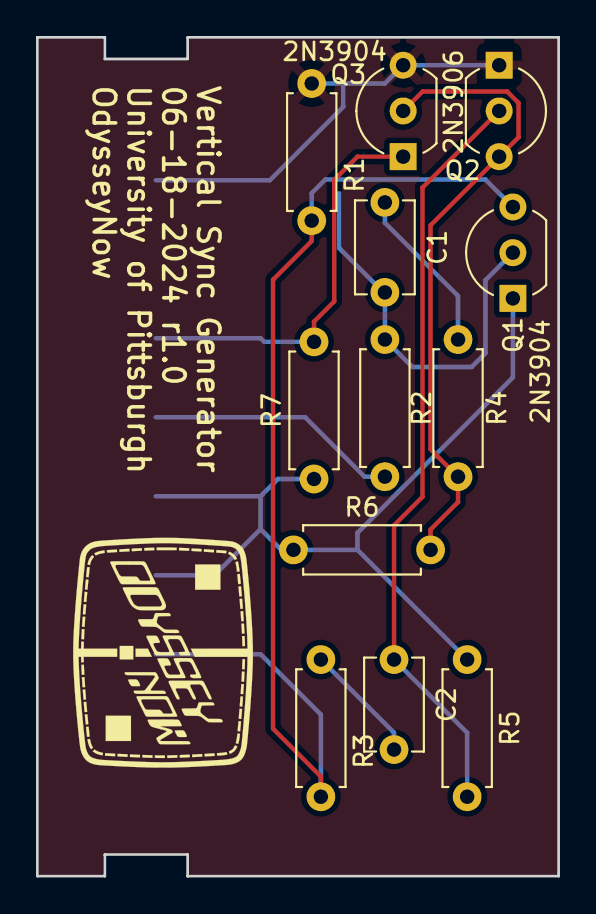
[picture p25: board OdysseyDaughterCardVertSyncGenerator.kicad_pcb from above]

Board: 2 copper layers, 29.0 x 46.6 mm, 14 parts (0 on the bottom side), 10 nets.

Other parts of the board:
X2: OdysseyNow_Logo; OdysseyNowLogo

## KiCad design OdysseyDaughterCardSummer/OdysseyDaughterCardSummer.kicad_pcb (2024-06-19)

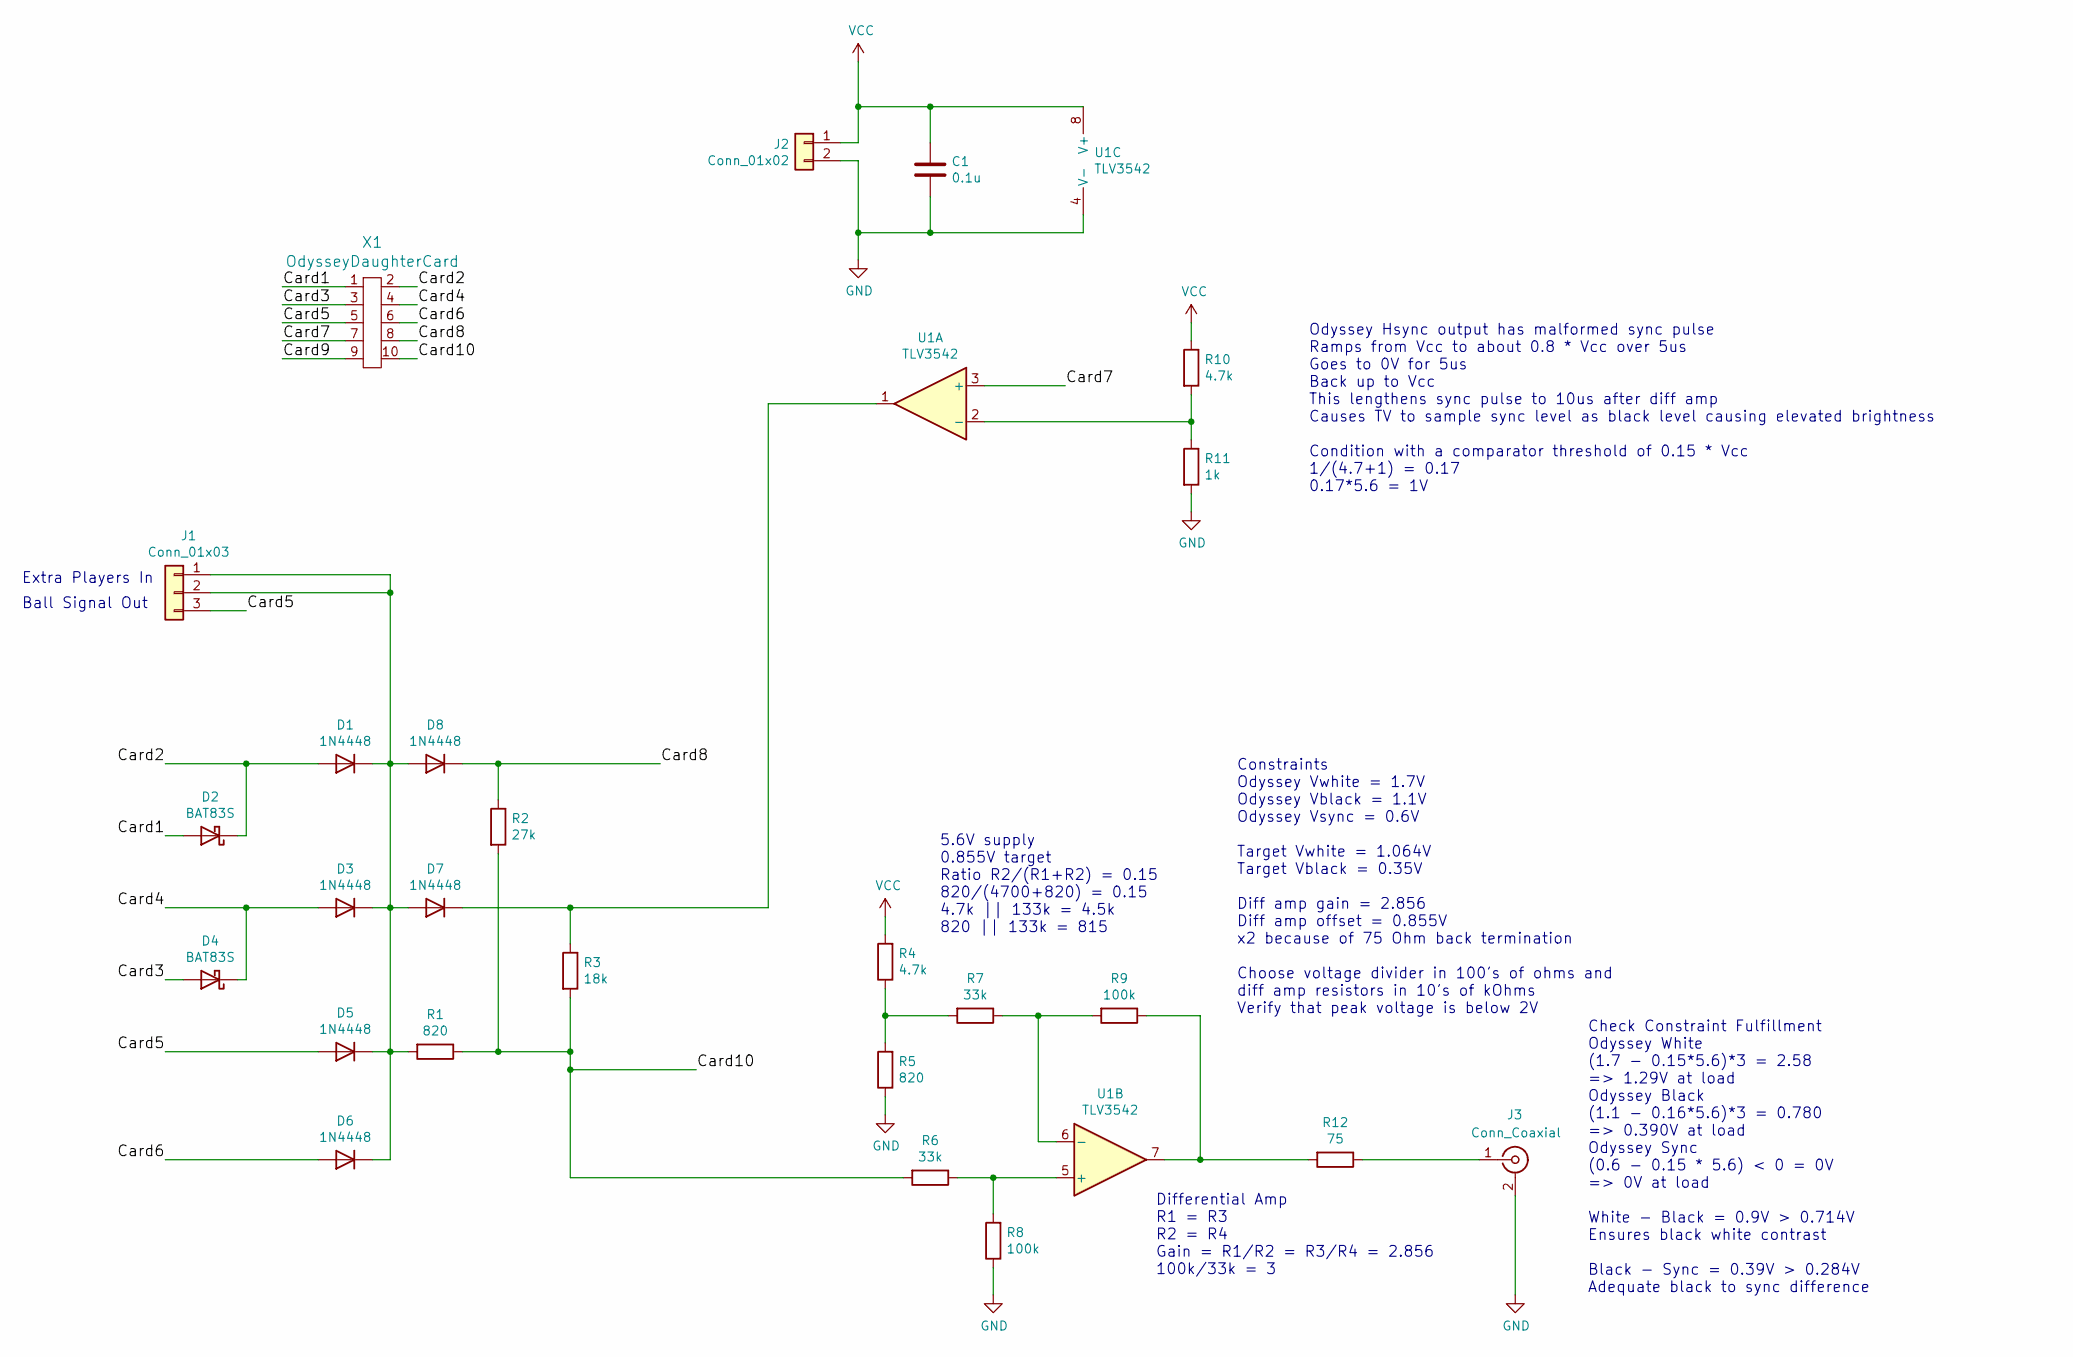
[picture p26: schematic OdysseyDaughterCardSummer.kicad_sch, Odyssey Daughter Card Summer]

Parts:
C1: 0.1u; C_Disc_D3.8mm_W2.6mm_P2.50mm
D1, D3, D5, D6, D7, D8: 1N4448; D_DO-35_SOD27_P7.62mm_Horizontal
D2, D4: BAT83S; D_DO-35_SOD27_P7.62mm_Horizontal
J1: Conn_01x03; PinHeader_1x03_P2.54mm_Vertical
J2: Conn_01x02; PinHeader_1x02_P2.54mm_Vertical
J3: Conn_Coaxial; PinHeader_1x02_P2.54mm_Vertical
R1, R5: 820; R_Axial_DIN0207_L6.3mm_D2.5mm_P7.62mm_Horizontal
R2: 27k; R_Axial_DIN0207_L6.3mm_D2.5mm_P7.62mm_Horizontal
R3: 18k; R_Axial_DIN0207_L6.3mm_D2.5mm_P7.62mm_Horizontal
R4, R10: 4.7k; R_Axial_DIN0207_L6.3mm_D2.5mm_P7.62mm_Horizontal
R6, R7: 33k; R_Axial_DIN0207_L6.3mm_D2.5mm_P7.62mm_Horizontal
R8, R9: 100k; R_Axial_DIN0207_L6.3mm_D2.5mm_P7.62mm_Horizontal
R11: 1k; R_Axial_DIN0207_L6.3mm_D2.5mm_P7.62mm_Horizontal
R12: 75; R_Axial_DIN0207_L6.3mm_D2.5mm_P7.62mm_Horizontal
U1: TLV3542; SOIC-8_3.9x4.9mm_P1.27mm
X1: OdysseyDaughterCard; Odyssey_Daughter_Card

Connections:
/Card1: D2.2 (A), X1.1
/Card2: D1.2 (A), D2.1 (K), X1.2
/Card3: D4.2 (A), X1.3
/Card4: D3.2 (A), D4.1 (K), X1.4
/Card5: D5.2 (A), J1.3, X1.5
/Card6: D6.2 (A), X1.6
/Card7: U1.3 (+), X1.7
/Card8: D8.1 (K), R2.1, X1.8
/Card9: X1.9
/Card10: R1.1, R2.2, R3.2, R6.2, X1.10
GND: C1.2, J2.2, J3.2 (Ext), R5.1, R8.1, R11.2, U1.4 (V-)
unnamed: D1.1 (K), D3.1 (K), D5.1 (K), D6.1 (K), D7.2 (A), D8.2 (A), J1.1, J1.2, R1.2
unnamed: D7.1 (K), R3.1, U1.1
unnamed: J3.1 (In), R12.1
unnamed: R4.1, R5.2, R7.2
unnamed: R9.1, R12.2, U1.7
unnamed: R10.2, R11.1, U1.2 (-)
unnamed: R6.1, R8.2, U1.5 (+)
unnamed: R7.1, R9.2, U1.6 (-)
VCC: C1.1, J2.1, R4.2, R10.1, U1.8 (V+)

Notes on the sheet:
Odyssey Hsync output has malformed sync pulse Ramps from Vcc to about 0.8 * Vcc over 5us Goes to 0V for 5us Back up to Vcc This lengthens sync pulse to 10us after diff amp Causes TV to sample sync level as black level causing elevated brightness Condition with a comparator threshold of 0.15 * Vcc 1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
Check Constraint Fulfillment Odyssey White (1.7 - 0.15*5.6)*3 = 2.58 => 1.29V at load Odyssey Black (1.1 - 0.16*5.6)*3 = 0.780 => 0.390V at load Odyssey Sync (0.6 - 0.15 * 5.6) < 0 = 0V => 0V at load White - Black = 0.9V > 0.714V Ensures black white contrast Black - Sync = 0.39V > 0.284V Adequate b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
Differential Amp R1 = R3 R2 = R4 Gain = R1/R2 = R3/R4 = 2.856 100k/33k = 3
Constraints Odyssey Vwhite = 1.7V Odyssey Vblack = 1.1V Odyssey Vsync = 0.6V Target Vwhite = 1.064V Target Vblack = 0.35V Diff amp gain = 2.856 Diff amp offset = 0.855V x2 because of 75 Ohm back termination Choose voltage divider in 100's of ohms and diff amp resistors in 10's of kOhms Verify that 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
5.6V supply 0.855V target Ratio R2/(R1+R2) = 0.15 820/(4700+820) = 0.15 4.7k || 133k = 4.5k 820 || 133k = 815
Extra Players In
Ball Signal Out

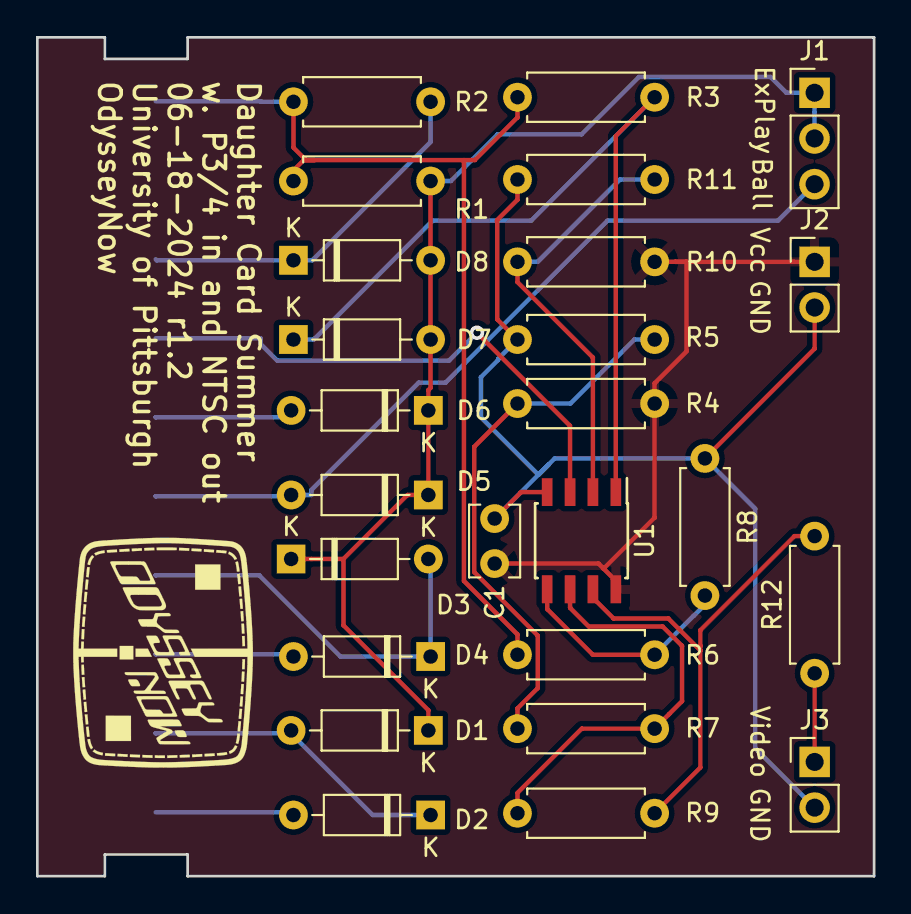
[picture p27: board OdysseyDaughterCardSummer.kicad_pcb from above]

Board: 2 copper layers, 46.5 x 46.6 mm, 27 parts (0 on the bottom side), 19 nets.

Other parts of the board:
X2: OdysseyNow_Logo; OdysseyNowLogo

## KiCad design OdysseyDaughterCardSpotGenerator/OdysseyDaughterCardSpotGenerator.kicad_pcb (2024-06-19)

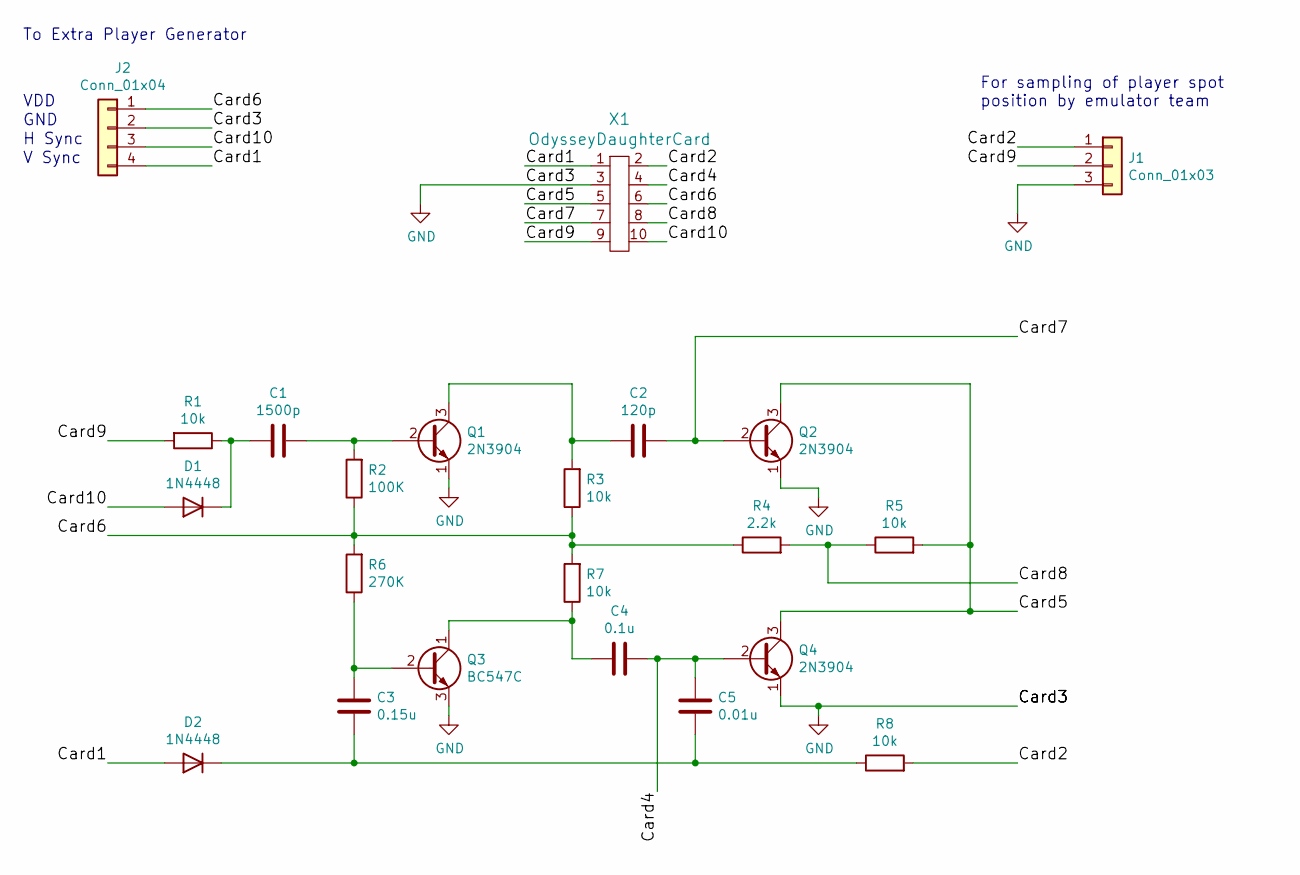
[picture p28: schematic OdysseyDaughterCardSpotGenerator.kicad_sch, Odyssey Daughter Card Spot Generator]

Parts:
C1: 1500p; C_Rect_L4.0mm_W2.5mm_P2.50mm
C2: 120p; C_Rect_L4.0mm_W2.5mm_P2.50mm
C3: 0.15u; C_Rect_L4.6mm_W5.5mm_P2.50mm_MKS02_FKP02
C4: 0.1u; C_Rect_L4.0mm_W2.5mm_P2.50mm
C5: 0.01u; C_Rect_L4.0mm_W2.5mm_P2.50mm
D1, D2: 1N4448; D_DO-35_SOD27_P7.62mm_Horizontal
J1: Conn_01x03; PinHeader_1x03_P2.54mm_Vertical
J2: Conn_01x04; PinHeader_1x04_P2.54mm_Vertical
Q1, Q2, Q4: 2N3904; TO-92_Inline_Wide
Q3: BC547C; TO-92_Inline_Wide
R1, R3, R5, R7, R8: 10k; R_Axial_DIN0207_L6.3mm_D2.5mm_P7.62mm_Horizontal
R2: 100K; R_Axial_DIN0207_L6.3mm_D2.5mm_P7.62mm_Horizontal
R4: 2.2k; R_Axial_DIN0207_L6.3mm_D2.5mm_P7.62mm_Horizontal
R6: 270K; R_Axial_DIN0207_L6.3mm_D2.5mm_P7.62mm_Horizontal
X1: OdysseyDaughterCard; Odyssey_Daughter_Card

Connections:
/Card1: D2.2 (A), J2.4, X1.1
/Card2: J1.1, R8.2, X1.2
/Card4: C4.2, C5.1, Q4.2 (B), X1.4
/Card5: Q2.3 (C), Q4.3 (C), R5.2, X1.5
/Card6: J2.1, R2.1, R3.1, R4.1, R6.2, R7.2, X1.6
/Card7: C2.1, Q2.2 (B), X1.7
/Card8: R4.2, R5.1, X1.8
/Card9: J1.2, R1.2, X1.9
/Card10: D1.2 (A), J2.3, X1.10
GND: J1.3, J2.2, Q1.1 (E), Q2.1 (E), Q3.3 (E), Q4.1 (E), X1.3
unnamed: C1.2, D1.1 (K), R1.1
unnamed: C3.1, C5.2, D2.1 (K), R8.1
unnamed: C1.1, Q1.2 (B), R2.2
unnamed: C2.2, Q1.3 (C), R3.2
unnamed: C3.2, Q3.2 (B), R6.1
unnamed: C4.1, Q3.1 (C), R7.1

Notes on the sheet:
VDD
For sampling of player spot position by emulator team
H Sync
GND
To Extra Player Generator
V Sync

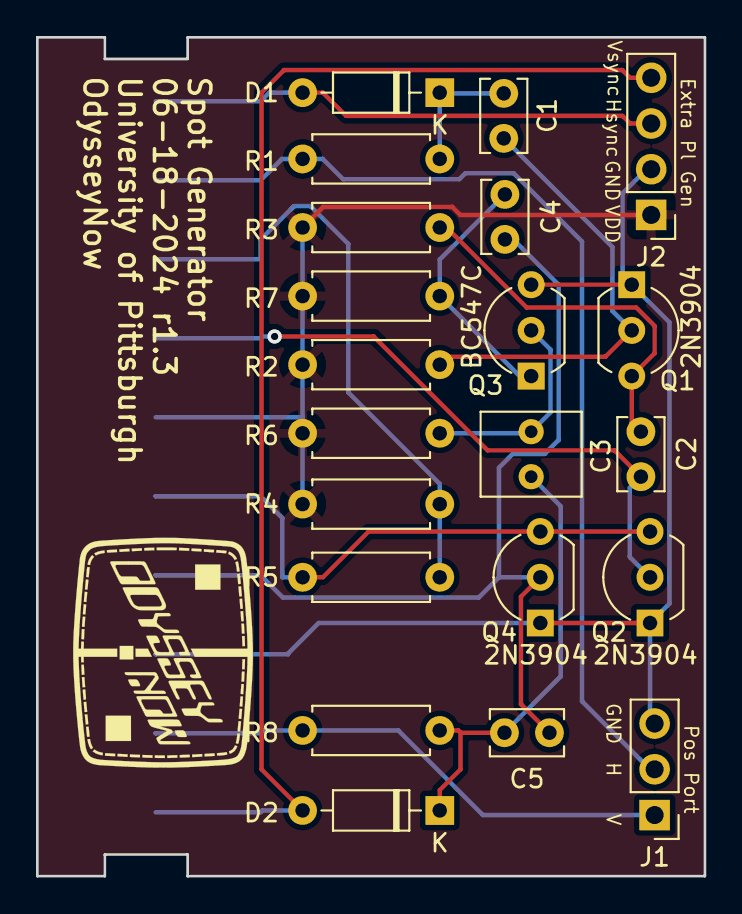
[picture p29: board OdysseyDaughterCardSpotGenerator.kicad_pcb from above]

Board: 2 copper layers, 37.1 x 46.6 mm, 23 parts (0 on the bottom side), 16 nets.

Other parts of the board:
X2: OdysseyNow_Logo; OdysseyNowLogo

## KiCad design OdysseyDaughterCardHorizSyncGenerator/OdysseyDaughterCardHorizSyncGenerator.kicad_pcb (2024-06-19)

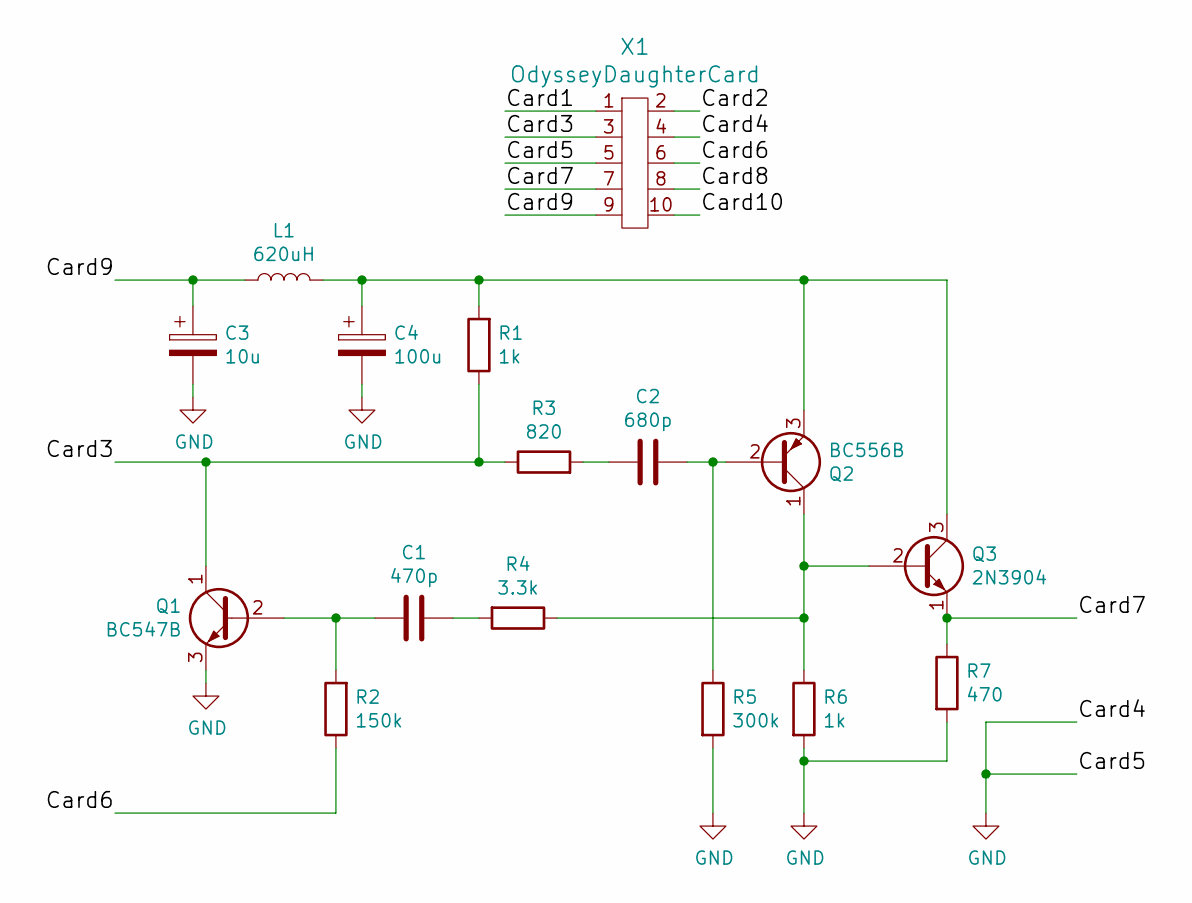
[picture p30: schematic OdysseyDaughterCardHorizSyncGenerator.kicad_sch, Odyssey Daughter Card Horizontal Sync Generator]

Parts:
C1: 470p; C_Disc_D5.1mm_W3.2mm_P5.00mm
C2: 680p; C_Disc_D5.1mm_W3.2mm_P5.00mm
C3: 10u; CP_Radial_D5.0mm_P2.00mm
C4: 100u; CP_Radial_D5.0mm_P2.00mm
L1: 620uH; L_Radial_D7.0mm_P3.00mm
Q1: BC547B; TO-92_Inline_Wide
Q2: BC556B; TO-92_Inline_Wide
Q3: 2N3904; TO-92_Inline_Wide
R1, R6: 1k; R_Axial_DIN0207_L6.3mm_D2.5mm_P7.62mm_Horizontal
R2: 150k; R_Axial_DIN0207_L6.3mm_D2.5mm_P7.62mm_Horizontal
R3: 820; R_Axial_DIN0207_L6.3mm_D2.5mm_P7.62mm_Horizontal
R4: 3.3k; R_Axial_DIN0207_L6.3mm_D2.5mm_P7.62mm_Horizontal
R5: 300k; R_Axial_DIN0207_L6.3mm_D2.5mm_P7.62mm_Horizontal
R7: 470; R_Axial_DIN0207_L6.3mm_D2.5mm_P7.62mm_Horizontal
X1: OdysseyDaughterCard; Odyssey_Daughter_Card

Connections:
/Card1: X1.1
/Card2: X1.2
/Card3: Q1.1 (C), R1.1, R3.1, X1.3
/Card6: R2.1, X1.6
/Card7: Q3.1 (E), R7.1, X1.7
/Card8: X1.8
/Card9: C3.1, L1.1, X1.9
/Card10: X1.10
GND: C3.2, C4.2, Q1.3 (E), R5.2, R6.2, R7.2, X1.4, X1.5
unnamed: C1.1, R4.2
unnamed: C2.2, R3.2
unnamed: C1.2, Q1.2 (B), R2.2
unnamed: C2.1, Q2.2 (B), R5.1
unnamed: Q2.1 (C), Q3.2 (B), R4.1, R6.1
unnamed: C4.1, L1.2, Q2.3 (E), Q3.3 (C), R1.2

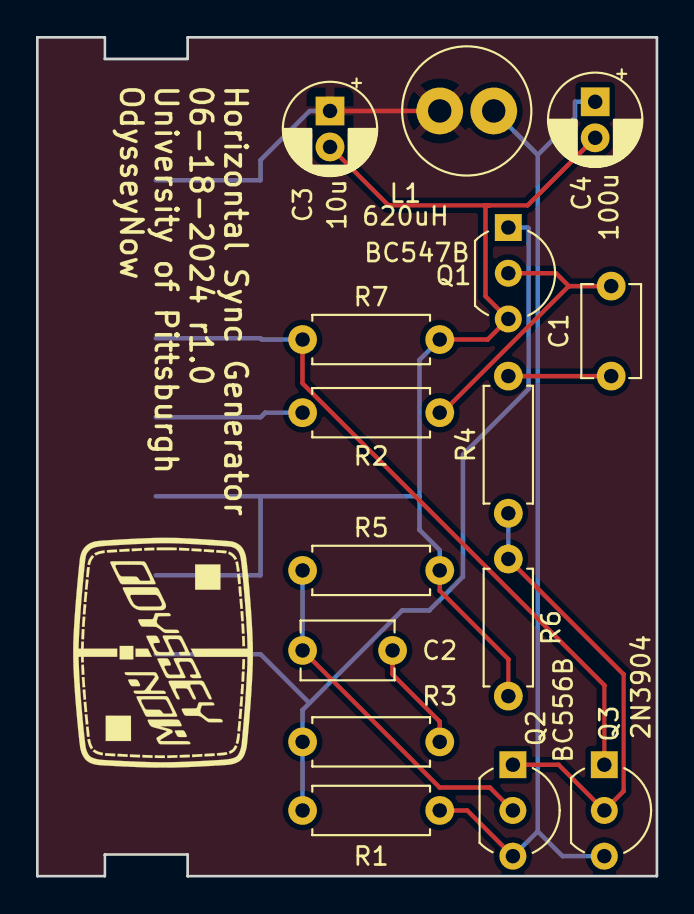
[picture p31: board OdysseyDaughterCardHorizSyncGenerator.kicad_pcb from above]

Board: 2 copper layers, 34.4 x 46.6 mm, 17 parts (0 on the bottom side), 11 nets.

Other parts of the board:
X1#2: OdysseyNow_Logo; OdysseyNowLogo

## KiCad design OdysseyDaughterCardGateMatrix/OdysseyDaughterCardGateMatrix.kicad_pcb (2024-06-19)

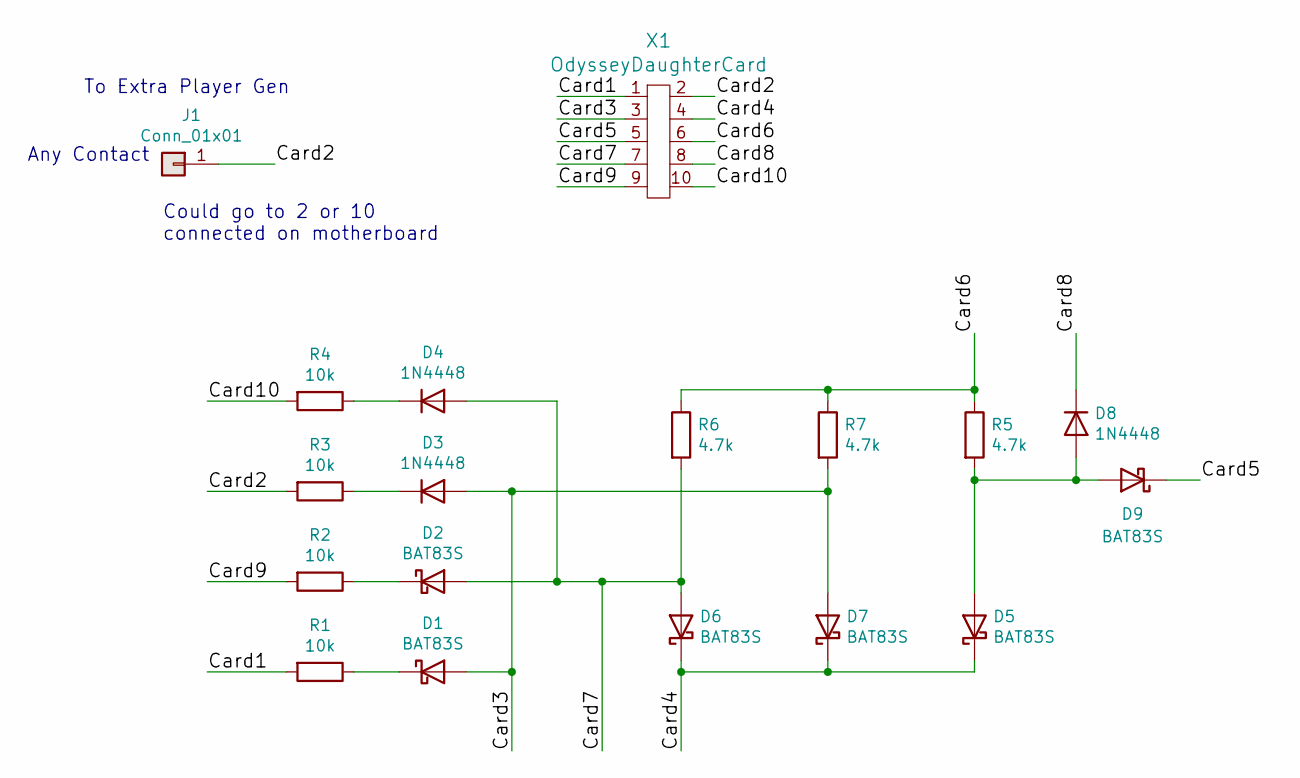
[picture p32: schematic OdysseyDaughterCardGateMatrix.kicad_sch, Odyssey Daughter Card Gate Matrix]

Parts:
D1, D2, D5, D6, D7, D9: BAT83S; D_DO-41_SOD81_P7.62mm_Horizontal
D3, D4, D8: 1N4448; D_DO-35_SOD27_P7.62mm_Horizontal
J1: Conn_01x01; PinHeader_1x01_P2.54mm_Vertical
R1, R2, R3, R4: 10k; R_Axial_DIN0207_L6.3mm_D2.5mm_P7.62mm_Horizontal
R5, R6, R7: 4.7k; R_Axial_DIN0207_L6.3mm_D2.5mm_P7.62mm_Horizontal
X1: OdysseyDaughterCard; Odyssey_Daughter_Card

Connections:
/Card1: R1.2, X1.1
/Card2: J1.1, R3.2, X1.2
/Card3: D1.2 (A), D3.2 (A), D7.2 (A), R7.2, X1.3
/Card4: D5.1 (K), D6.1 (K), D7.1 (K), X1.4
/Card5: D9.1 (K), X1.5
/Card6: R5.1, R6.1, R7.1, X1.6
/Card7: D2.2 (A), D4.2 (A), D6.2 (A), R6.2, X1.7
/Card8: D8.1 (K), X1.8
/Card9: R2.2, X1.9
/Card10: R4.2, X1.10
unnamed: D1.1 (K), R1.1
unnamed: D2.1 (K), R2.1
unnamed: D3.1 (K), R3.1
unnamed: D4.1 (K), R4.1
unnamed: D5.2 (A), D8.2 (A), D9.2 (A), R5.2

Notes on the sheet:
Could go to 2 or 10 connected on motherboard
To Extra Player Gen
Any Contact

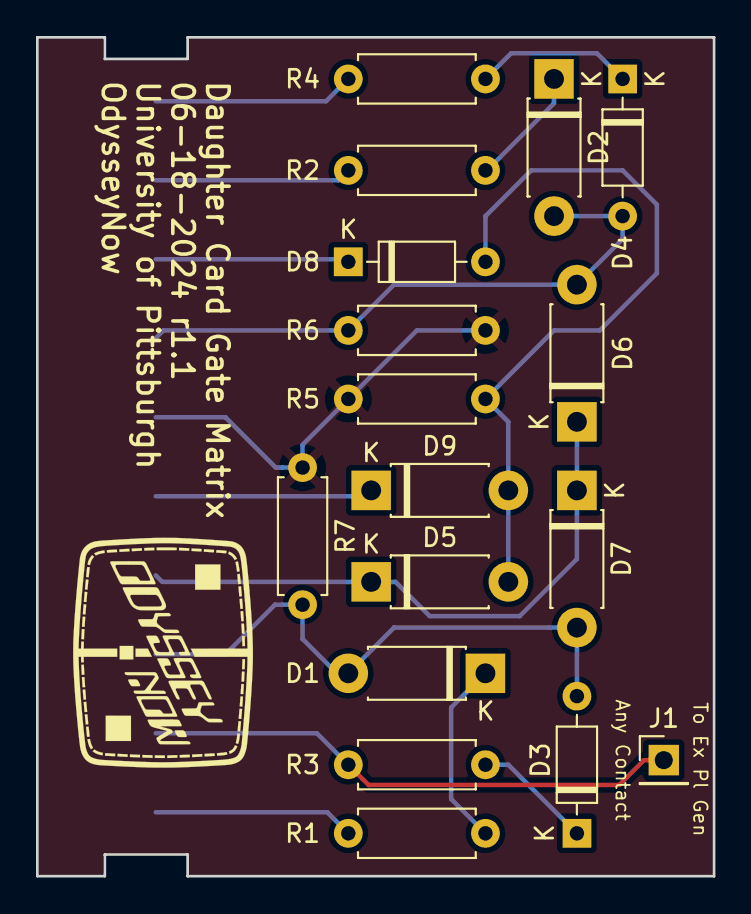
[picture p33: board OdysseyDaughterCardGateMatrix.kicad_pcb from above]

Board: 2 copper layers, 37.6 x 46.6 mm, 19 parts (0 on the bottom side), 15 nets.

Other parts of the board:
X1#2: OdysseyNow_Logo; OdysseyNowLogo

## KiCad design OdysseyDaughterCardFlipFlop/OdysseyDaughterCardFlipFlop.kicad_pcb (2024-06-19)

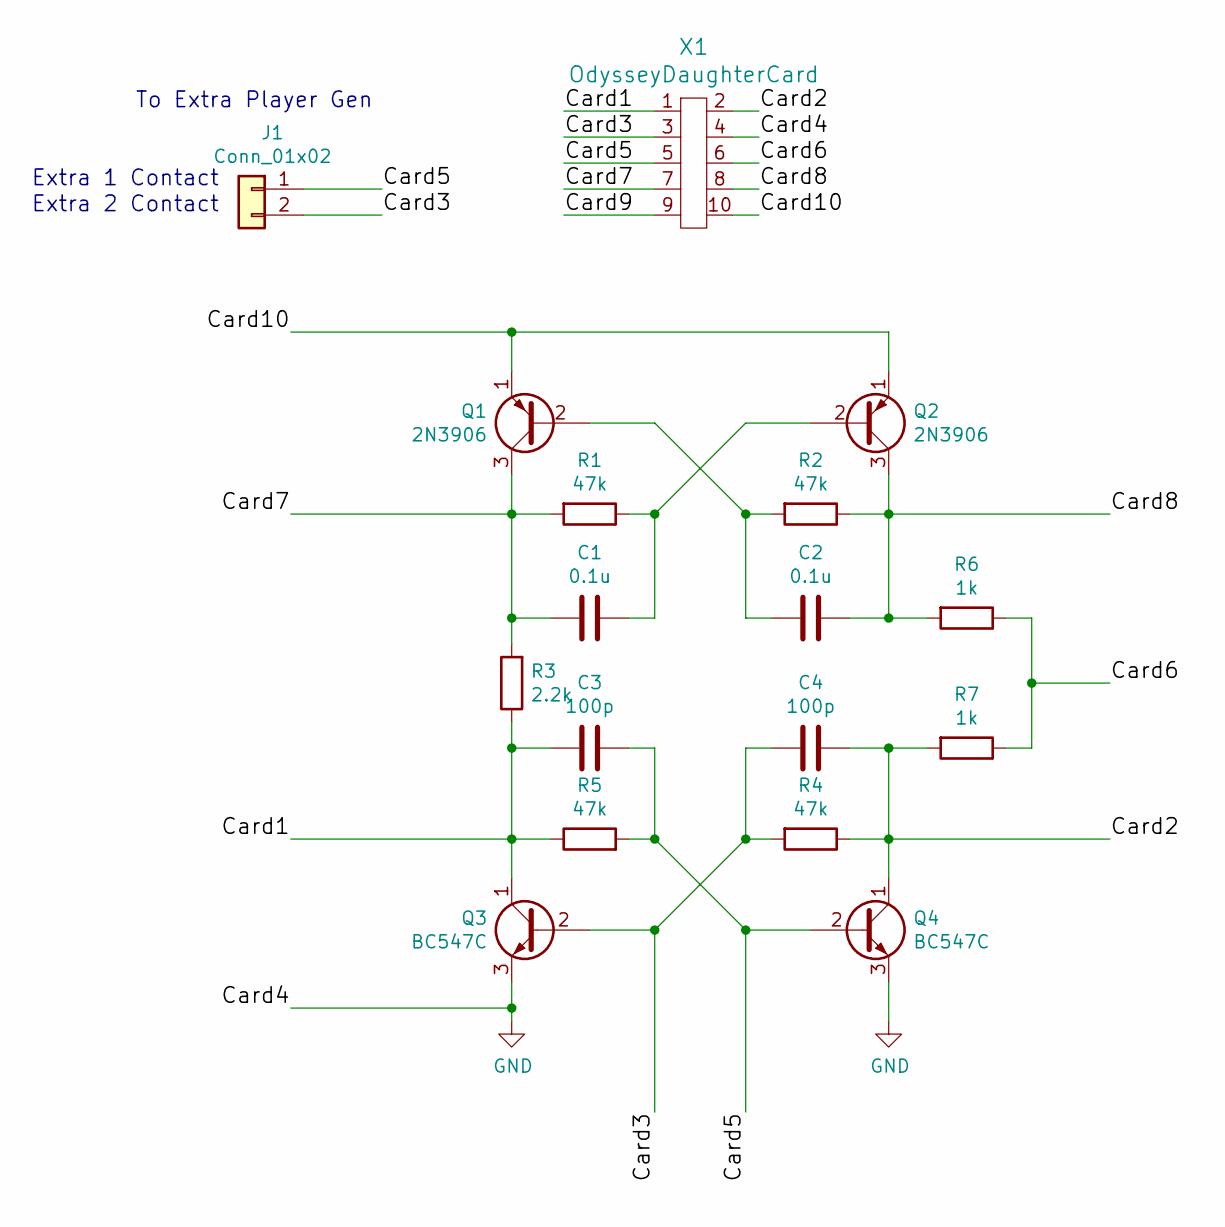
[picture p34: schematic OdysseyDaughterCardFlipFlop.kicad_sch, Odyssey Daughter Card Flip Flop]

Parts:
C1, C2: 0.1u; C_Disc_D5.1mm_W3.2mm_P5.00mm
C3, C4: 100p; C_Disc_D5.1mm_W3.2mm_P5.00mm
J1: Conn_01x02; PinHeader_1x02_P2.54mm_Vertical
Q1, Q2: 2N3906; TO-92_Inline_Wide
Q3, Q4: BC547C; TO-92_Inline_Wide
R1, R2, R4, R5: 47k; R_Axial_DIN0207_L6.3mm_D2.5mm_P7.62mm_Horizontal
R3: 2.2k; R_Axial_DIN0207_L6.3mm_D2.5mm_P7.62mm_Horizontal
R6, R7: 1k; R_Axial_DIN0207_L6.3mm_D2.5mm_P7.62mm_Horizontal
X1: OdysseyDaughterCard; Odyssey_Daughter_Card

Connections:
/Card1: C3.2, Q3.1 (C), R3.1, R5.1, X1.1
/Card2: C4.1, Q4.1 (C), R4.1, R7.2, X1.2
/Card3: C4.2, J1.2, Q3.2 (B), R4.2, X1.3
/Card5: C3.1, J1.1, Q4.2 (B), R5.2, X1.5
/Card6: R6.1, R7.1, X1.6
/Card7: C1.2, Q1.3 (C), R1.2, R3.2, X1.7
/Card8: C2.1, Q2.3 (C), R2.1, R6.2, X1.8
/Card9: X1.9
/Card10: Q1.1 (E), Q2.1 (E), X1.10
GND: Q3.3 (E), Q4.3 (E), X1.4
unnamed: C2.2, Q1.2 (B), R2.2
unnamed: C1.1, Q2.2 (B), R1.1

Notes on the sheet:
To Extra Player Gen
Extra 2 Contact
Extra 1 Contact

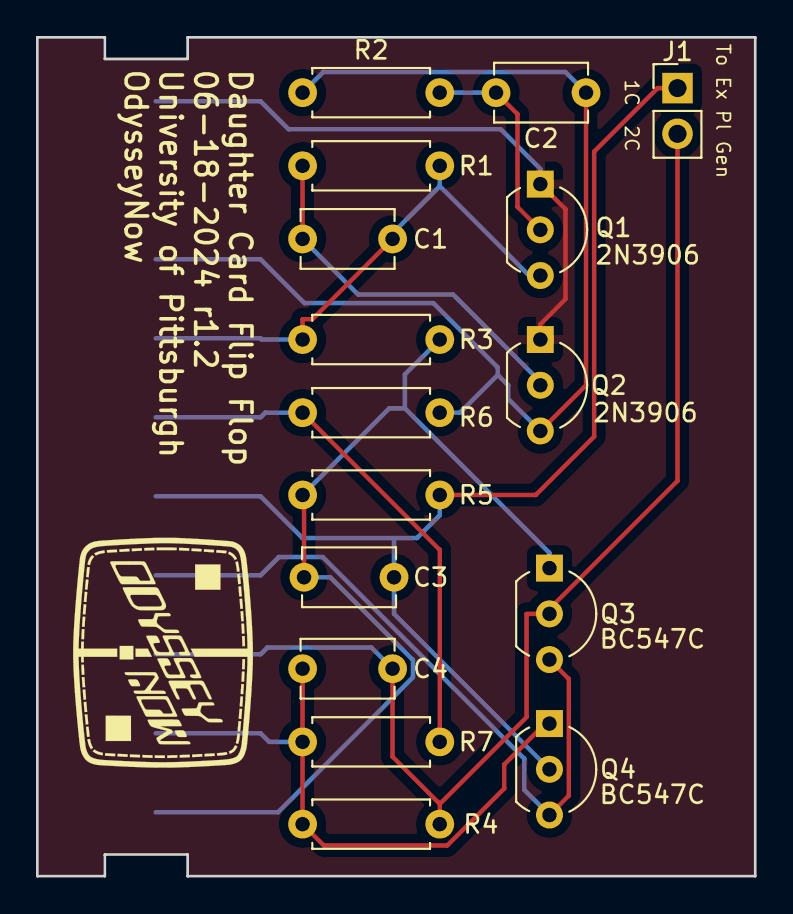
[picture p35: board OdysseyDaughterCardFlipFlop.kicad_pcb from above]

Board: 2 copper layers, 39.9 x 46.6 mm, 18 parts (0 on the bottom side), 11 nets.

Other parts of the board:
X1#2: OdysseyNow_Logo; OdysseyNowLogo

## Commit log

2022-08-02 Squashed legacy Vertical Sync Generator repository history
    Gitignore
    Initial Version
    Add meta
    Add labels to connector
    Initial commit of Vertical Sync Generator
    V0.1 gerbers
    Gerber settings
    Change hole size of transistors to meet allPCB specs
    Regenerated gerbers
    Fix silk screen labeling (did not make new gerbers)
    Bump rev number and regenerate gerbers
    Add note about BLAK vs BK12 console revisions
    [OdysseyDaughterCardVertSyncGenerator-B.Cu.gbr, OdysseyDaughterCardVertSyncGenerator-B.Mask.gbr, OdysseyDaughterCardVertSyncGenerator-B.SilkS.gbr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]
2022-08-02 Move legacy Vertical Sync Generator out of root
    [OdysseyDaughterCardVertSyncGenerator-B.Cu.gbr, OdysseyDaughterCardVertSyncGenerator-B.Mask.gbr, OdysseyDaughterCardVertSyncGenerator-B.SilkS.gbr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]
2022-08-02 Squashed legacy Horizontal Sync Generator repository history
    V0.1 of the horizontal sync generator
    Shrink transistor hole sizes to 0.65mm from 0.75mm
    V0.3 fixes backwards transistor in schematic, regenerated gerbers
    V0.3 dimensions
    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
    [OdysseyDaughterCardHorizSyncGenerator-B.Cu.gbr, OdysseyDaughterCardHorizSyncGenerator-B.Mask.gbr, OdysseyDaughterCardHorizSyncGenerator-B.SilkS.gbr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]
2022-08-02 Move legacy Horizontal Sync Generator out of root
    [OdysseyDaughterCardHorizSyncGenerator-B.Cu.gbr, OdysseyDaughterCardHorizSyncGenerator-B.Mask.gbr, OdysseyDaughterCardHorizSyncGenerator-B.SilkS.gbr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]
2022-08-02 Squash legacy Gate Matrix repository history
    Initial unrouted gate matrix
    Routed gate matrix
    Fix component types in schematic
    Shrink PCB
    Generate V0.1 gerbers
    Update gerbers to use protel extensions
    Add forgotten trace
    Change diode types, bump rev #
    R1.0 Add header for extra player generator
    Fixup dimensions
    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
    [OdysseyDaughterCardGateMatrix-B.Cu.gbr, OdysseyDaughterCardGateMatrix-B.Mask.gbr, OdysseyDaughterCardGateMatrix-B.SilkS.gbr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]
2022-08-02 Move legacy Gate Matrix out of root
    [OdysseyDaughterCardGateMatrix-B.Cu.gbr, OdysseyDaughterCardGateMatrix-B.Mask.gbr, OdysseyDaughterCardGateMatrix-B.SilkS.gbr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]
2022-08-02 Squash legacy Spot Generator repository history
    Initial schematic of spot generator
    Layout components on PCB
    Use autorouter
    Fix PCB component annotations
    Generate gerbers for V0.1
    1.0 add port for emulator team
    Update dimensions
    R1.1 add header for extra player gen
    Fix Hsync/Vsync out silkscreen markings
    Add gnd and vdd to extra player interface port still R1.2
    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
    [OdysseyDaughterCardSpotGenerator-B.Cu.gbr, OdysseyDaughterCardSpotGenerator-B.Mask.gbr, OdysseyDaughterCardSpotGenerator-B.SilkS.gbr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]
2022-08-02 Move legacy Spot Generator out of root
    [OdysseyDaughterCardSpotGenerator-B.Cu.gbr, OdysseyDaughterCardSpotGenerator-B.Mask.gbr, OdysseyDaughterCardSpotGenerator-B.SilkS.gbr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]
2022-08-02 Squash legacy Flip Flop repository history
    Use template for flip flop
    V0.1 of the flip flop daughter card
    Include output directory in pcb file
    R1.0 Flip-flop add header for extra player generator
    Update to R1.1, remove power output for extra player generator
    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
    [OdysseyDaughterCardFlipFlop-B.Cu.gbr, OdysseyDaughterCardFlipFlop-B.Mask.gbr, OdysseyDaughterCardFlipFlop-B.SilkS.gbr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]
2022-08-02 Move legacy Flip Flop out of root
    [OdysseyDaughterCardFlipFlop-B.Cu.gbr, OdysseyDaughterCardFlipFlop-B.Mask.gbr, OdysseyDaughterCardFlipFlop-B.SilkS.gbr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]
2022-08-02 Squash legacy Summer repository history
    Use template to make summer card
    Summer V0.1 with 2 extra player inputs
    R1.0 remove extra player hardware and replace with single port
    Don't keep zips of gerbers in vcs
    Typo in dimensions
    R1.1 with video mod pre layout
    R1.1 gerbs and board NTSC generator
    Matt added pad to expansion header on 05-22-20
    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
    [OdysseyDaughterCardSummer-B.Cu.gbr, OdysseyDaughterCardSummer-B.Mask.gbr, OdysseyDaughterCardSummer-B.SilkS.gbr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]
2022-08-02 Move legacy Summer out of root
    [OdysseyDaughterCardSummer-B.Cu.gbr, OdysseyDaughterCardSummer-B.Mask.gbr, OdysseyDaughterCardSummer-B.SilkS.gbr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]
2022-08-02 Squash legacy Template repository history
    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
    [OdysseyDaughterCardTemplate.kicad_pcb, OdysseyDaughterCardTemplate.sch]
2022-08-02 Move legacy Template out of root
    [OdysseyDaughterCardTemplate.kicad_pcb, OdysseyDaughterCardTemplate.sch]
2022-08-02 OdysseyDaughterCardFlipFlop: Open and close in Kicad 6, fix symbol library path
    [OdysseyDaughterCardFlipFlop.kicad_pcb, OdysseyDaughterCardFlipFlop.kicad_sch, OdysseyDaughterCardFlipFlop.sch]
2022-08-02 OdysseyDaughterCardGateMatrix: Open and close in KiCad 6, fix symbol library path
    [OdysseyDaughterCardGateMatrix.kicad_pcb, OdysseyDaughterCardGateMatrix.kicad_sch, OdysseyDaughterCardGateMatrix.sch]
2022-08-02 OdysseyDaughterCardHorizSyncGenerator: Open and close in KiCad 6, fix symbol library paths
    [OdysseyDaughterCardHorizSyncGenerator.kicad_pcb, OdysseyDaughterCardHorizSyncGenerator.kicad_sch, OdysseyDaughterCardHorizSyncGenerator.sch]
2022-08-02 OdysseyDaughterCardSpotGenerator: Open and close in KiCad 6, fix symbol library path
    [OdysseyDaughterCardSpotGenerator.kicad_pcb, OdysseyDaughterCardSpotGenerator.kicad_sch, OdysseyDaughterCardSpotGenerator.sch]
2022-08-02 OdysseyDaughterCardSummer: Open and close in KiCad 6, fix symbol library path
    [OdysseyDaughterCardSummer.kicad_pcb, OdysseyDaughterCardSummer.kicad_sch, OdysseyDaughterCardSummer.sch]
2022-08-02 OdysseyDaughterCardTemplate: Open and close in KiCad 6, fix symbol library pathwq
    [OdysseyDaughterCardTemplate.kicad_pcb, OdysseyDaughterCardTemplate.kicad_sch, OdysseyDaughterCardTemplate.sch]
2022-08-02 OdysseyDaughterCardVertSyncGenerator: Open and close in KiCad 6, fix symbol library path
    [OdysseyDaughterCardVertSyncGenerator.kicad_pcb, OdysseyDaughterCardVertSyncGenerator.kicad_sch, OdysseyDaughterCardVertSyncGenerator.sch]
2024-06-19 OdysseyDaughterCardFlipFlop wider transistor footprint, logo, pours, pdfs, images, 3d model
    [OdysseyDaughterCardFlipFlop-B.Cu.gbr, OdysseyDaughterCardFlipFlop-B.Mask.gbr, OdysseyDaughterCardFlipFlop-B.SilkS.gbr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]
2024-06-19 OdysseyDaughterCardGateMatrix wider transistor footprint, add logo, generate pdf, images, 3d models
    [OdysseyDaughterCardGateMatrix-B.Cu.gbr, OdysseyDaughterCardGateMatrix-B.Mask.gbr, OdysseyDaughterCardGateMatrix-B.SilkS.gbr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]
2024-06-19 OdysseyDaughterCardHorizSyncGenerator wider transistor footprint, add logo, generate pdf, images, 3d models
    [OdysseyDaughterCardHorizSyncGenerator-B.Cu.gbr, OdysseyDaughterCardHorizSyncGenerator-B.Mask.gbr, OdysseyDaughterCardHorizSyncGenerator-B.SilkS.gbr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]
2024-06-19 OdysseyDaughterCardSpotGenerator wider transistor footprint, add logo, generate pdf, images, 3d models
    [OdysseyDaughterCardSpotGenerator-B.Cu.gbr, OdysseyDaughterCardSpotGenerator-B.Mask.gbr, OdysseyDaughterCardSpotGenerator-B.SilkS.gbr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]
2024-06-19 OdysseyDaughterCardSummer add logo, generate pdf, images, 3d models
    [OdysseyDaughterCardSummer-B.Cu.gbr, OdysseyDaughterCardSummer-B.Mask.gbr, OdysseyDaughterCardSummer-B.SilkS.gbr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]
2024-06-19 OdysseyDaughterCardTemplate add logo
    [OdysseyDaughterCardTemplate.kicad_pcb, OdysseyDaughterCardTemplate.kicad_sch]
2024-06-19 OdysseyDaughterCardVertSyncGenerator wider transistor footprint, add logo, generate pdf, images, 3d models
    [OdysseyDaughterCardVertSyncGenerator-B.Cu.gbr, OdysseyDaughterCardVertSyncGenerator-B.Mask.gbr, OdysseyDaughterCardVertSyncGenerator-B.SilkS.gbr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]
2024-06-29 Add bill of materials
    [OdysseyDaughtCardsBillOfMaterials.xlsx]
